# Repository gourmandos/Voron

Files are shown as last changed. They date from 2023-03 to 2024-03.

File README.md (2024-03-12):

This repo is a collection of the info gathered in preparationa dn during the completion fo my built, hopefully it serves others.  
As always, make your own choices - the Trident is a great machine in it's stock form, none of this is necessary.

# [RESOURCES](/Resources.md)

General stuff

# [ACCESORIES & MODS](/ThingsToPrint.md)

Things to print

# [ELECTRONICS](/Electronics.md)

## [Wiring](/Electronics.md#wiring)

# [RPI STUFF](/RPi.md)

# [CONFIG STUFF](/Klipper&Config.md)

# [WHERE TO BUY](/$$$.md)

---

# MODS

[ADXL Nozzle mount](https://github.com/Armchair-Engineering/ADXL-Mounts)

[Printed top hat](https://github.com/jakub874/Jakub3DPrinterMods/tree/main/Tophat)

## Purge & Scrub

> UPDATE [HERE](https://discord.com/channels/712144492563791922/712144492563791925/1103200498649145364)

https://www.printables.com/model/174526-trident-mount-for-decontaminator-purge-bucket-nozz  
https://drive.google.com/drive/folders/1WdAFon_ZR4lkPwNxH9pqIMwNEeP3NHKx

To be used in combination:

[Double wiper decontaminator](https://drive.google.com/drive/u/0/folders/1z-9KpVIce1BrdW45PiMQcnK1v2ausvbj)  
Credits @Sushei#3125 on Discord

[Trident decontaminator mount](https://www.teamfdm.com/files/file/617-trident-decontaminator_mount_rightstl/)

[Macros](https://github.com/VoronDesign/VoronUsers/tree/master/orphaned_mods/printer_mods/edwardyeeks/Decontaminator_Purge_Bucket_&_Nozzle_Scrubber/Macros)

[Jig](/stl-3mf/Wiper_Jig.stl) for cutting the icetray made wiper.

[Voron Trident Silicone Nozzle Park](https://github.com/Esoterical/PrinterMods/tree/main/Trident%20Nozzle%20Park)

## Exhaust

[Magnetic Exhaust Grill Cover](https://github.com/VoronDesign/VoronUsers/tree/master/printer_mods/falo/magnetic_grill_cover)

[VEFACH - Voron Exhaust Filter Activated Coal + Hepa](https://mods.vorondesign.com/detail/aLS5rOxzGybD4FhVzCKNQ)

[Exhaust Adapter 100mm](https://mods.vorondesign.com/detail/nKx3H8zQ6brp42wN5cgA)

[Exhaust cover with pneumatic passthrough](https://github.com/VoronDesign/VoronUsers/tree/master/printer_mods/Fiction/Exhaust_cover)

[LDO exhaust cover](/stl-3mf/LDO_exhaust_cover.3mf)  
Source: [LDO Trident repo](https://github.com/MotorDynamicsLab/LDOVoronTrident/tree/master/STLs/Angled%20Exhaust%20Cover)

[Roomba 800/900 HEPA Filter Box](https://www.teamfdm.com/files/file/740-voron-24-roomba-800900-hepa-filter-box/)

## Insulation support clips

Used to hold insulation on the inside against the PC panels --- UNTESTED !!!  
[Deck Panel Support Clips](https://github.com/VoronDesign/VoronUsers/tree/master/printer_mods/wile-e1/Deck_Panel_Support_Clips)

## Electronic bay

[Trident Inverted Electronics Bay](https://github.com/VoronDesign/VoronUsers/tree/master/printer_mods/LoganFraser/TridentInvertedElectronics)

[SSD DIN mount](/stl-3mf/SSD%20DIN%20mount/), inspired from [SSD DIN bracket](https://github.com/VoronDesign/VoronUsers/tree/master/printer_mods/slitte/ssd_bracket)

[Pi fan with SSD mount](https://www.printables.com/model/225282-the-terrapi-x-prusa-edition-single-ssd-case-for-ra)

[Screw terminal cover for LRS PSU](https://github.com/VoronDesign/VoronUsers/tree/master/printer_mods/samwiseg0/lrs_screw_terminal_cover)

[Cable tie mount for DIN rail](https://github.com/VoronDesign/VoronUsers/tree/master/printer_mods/aeresov/cable_tie_DIN_mount)

[Cable tie double-sided tape anchor](/stl-3mf/Ziptie%20DS-tape%20cable%20anchor.3mf)

[Stiffer generic DIN bracket](https://github.com/Ramalama2/Voron-2-Mods/tree/main/DinClips)

[AliExpress Wagos DIN bracket](https://github.com/VoronDesign/VoronUsers/tree/master/printer_mods/Empusas/Terminal_Blocks_NC933_SPL-62)

[Octopus Pro FanCase aka Octoglasses](https://github.com/Ramalama2/Voron-2-Mods/tree/main/Octopus_Pro_FanCase)

[Octopus driver cooling](/stl-3mf/Octopus%20driver%20cooling/)
Credits to BioShank (Discord)

[Misumi Cable Clip](https://github.com/Ramalama2/Voron-2-Mods/tree/main/Misumi_Cable_Clip)

[Cable duct](https://github.com/GP3DS/Voron-Mods/tree/main/Cable_Duct)

[Cable canal](https://www.thingiverse.com/thing:3062013)

[Remix of RyanDam's Cable Management Duct](https://www.teamfdm.com/files/file/724-remix-of-ryandams-cable-management-duct-for-voron-printers/)

## Skirts

[Integrated accent mesh](https://www.youtube.com/watch?v=K6sHfXldK4k)

[ADXL keystone](https://www.teamfdm.com/files/file/358-adxl345-skirt-keystone/)

[Trident right skirt switch](https://github.com/VoronDesign/VoronUsers/tree/master/printer_mods/DerekBackus/Right_Skirt_Switch)

[Skirt push buttons - *Bouncy Mouse*](https://github.com/Jaans/Voron-Printer-Mods/tree/main/Bouncy-Mouse)

## Screen mount

[Waveshare 5'' screen](/stl-3mf/Waveshare%205''%20screen.3mf)

Fits [5inch DSI LCD](https://www.waveshare.com/wiki/5inch_DSI_LCD) model - Remixed from [sttts](https://github.com/VoronDesign/VoronUsers/tree/master/printer_mods/sttts/Waveshare-5.5-inch-HDMI-AMOLED) & [Paul_GD](https://www.printables.com/model/178195-waveshare-5-dsi-touchscreen-for-bear-21)

## LEDs

[Daylight bracket 2020](https://github.com/VoronDesign/Voron-Hardware/blob/master/Daylight/STL/Brackets_2020.stl)

[LED clip, by eddietheengineer](https://github.com/VoronDesign/VoronUsers/blob/master/printer_mods/eddie/LED_Bar_Clip)

[LED corner, by Ramalama](https://github.com/Ramalama2/Voron-2-Mods/tree/main/Deprecated/Misumi_Led_Corners)

[Voron 2.2 led light bar mount](https://github.com/VoronDesign/Voron-2/blob/Voron2.2/STLs/VORON2.2/Misc)

[Rainbow BARF SB logo](https://github.com/tanaes/whopping_Voron_mods/tree/main/LEDs/Rainbow_Barf_Logo_LED)

[LED baffles](https://github.com/AdamV3D/V3D-Voron-Mods/tree/main/Daylight_on_a_Stick/Mounts/V2.4/V2)

## Doomy

[Sidepack](https://github.com/3DPrintingMods/VoronTrident-Sidepack)

[EZ Bake](https://github.com/FrankenVoron/Trident-EZBake)

## Belted Z

[Orion Tri-belt](https://github.com/bythorsthunder/Orion-Tri-Belt)

[Voron Trident - Belted Z motion](https://github.com/3DPrintingMods/VoronTrident-BeltedZ)

[VT Belted Z](https://github.com/MathematicalPotato/Voron_Mods/tree/main/VT_Belted_Z)

Voron Trident - K3Z

## AWD

[Fourbie](https://github.com/MakerBogans/Fourbie)

[TridentAWD](https://github.com/Fuffledag22/TridentAWD)

aTinyShellScript Voron v2.4 AWD [Mod](https://docs.atinyshellscript.com/v2.4/awd/#nema17-bearing-idler-stacks)

Modified version of aTinyShellScript's AWD [MOD](https://mpx.wiki/VORON-AWD-2WD-MOD/intro)

## Filament guide

[Through panel with 360° joint](https://github.com/DeBau/VoronMods/tree/main/Top%20Bowden%20Guide)

[PTFE tube guide with F695 bearing - TOP REAR extrusion](/stl-3mf/Bowden_Guide_-_Long-Arm_v1-F695.3mf)  
Credits to [GalvanicGlaze](https://github.com/GalvanicGlaze/Voron_Mods/tree/main/Trident%20Bowden%20tube%20PTFE%20guide) & [top_gun_de](https://discord.com/channels/460117602945990666/635687829254701107/1026616435805519902) 
    
## Smart Filament Sensor

[SFS V2.0 Pivot Mount](https://www.thingiverse.com/thing:6275328)

[Exhaust cover and BTT Smart Filament Sensor mount](https://github.com/VoronDesign/VoronUsers/tree/master/printer_mods/Fiction/Exhaust_cover_SFS)

[BTT Smart Filament Sensor frame mount](https://github.com/airway38/Voron-Modifications/tree/main/BTT%20SFS%20Frame%20Mount)

[BTT Smart Filament Sensor mount](https://www.printables.com/model/220585-voron-v2-btt-smart-filament-sensor-mount)

[BTT filament motion sensor mount](https://github.com/VoronDesign/VoronUsers/tree/master/printer_mods/Empusas/BTT_Filament_Motion_Sensor_Mount)

## Extruder

[Sherpa Crew Mini](https://github.com/jrlomas/Sherpa-Crew-Mini) - The issue 6/602 slayer

[Fixed Idler Sherpa Micro](https://github.com/Annex-Engineering/Annex-Engineering_User_Mods/tree/main/Extruders/Sherpa_Micro/Extruder_Mods/Churls_Fixed_Idler_Micro)

# ACCESORIES

## Filter

[Rebreather_XL](https://github.com/Annex-Engineering/Annex-Engineering_User_Mods/tree/main/Misc/Rebreather/Kirby-RebreatherXL)

Trident mount [HERE](/stl-3mf/Rebreather%20XL/)

> Credits to `UPDATE`

[Nevermore Micro v6](https://github.com/nevermore3d/Nevermore_Micro/tree/master/V6)  
>Community nods available `TO BE UPDATED`

[Nevermore StealthMax](https://github.com/nevermore3d/StealthMax) with [direct-mount onto a panel](https://github.com/nevermore3d/StealthMax/tree/main/STL/Direct-On-Panel_Mount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)

[Rebreather](https://github.com/Annex-Engineering/Rebreather)

[The_Filter](https://github.com/nateb16/VoronUsers/tree/master/printer_mods/nateb16/THE_FILTER)

[Activated Carbon Filter 7530](https://github.com/yasuoki/ActivatedCarbonFilter7530)

[Trident shaft](https://github.com/thomas-ewing/trident-shaft)

[Evermore](https://github.com/TodWulff/Evermore-Chamber-Filter)

[MFNano](https://github.com/MapleLeafMakers/MFNano)

## Dust & purge management

[Z-Motor cover](https://www.teamfdm.com/files/file/555-z-motor-cover-trident/?tab=details)

[2020 profile covers](https://mods.vorondesign.com/detail/8PtM9BKgRdBUN7CZ8g6Q)

[6mm slot cover](https://mods.vorondesign.com/detail/ZKJgu7OwMNB1xAKRrYSYeg)

## MMU

[TradRack](https://github.com/Annex-Engineering/TradRack)

[piKa - filament buffer](https://github.com/geoffrey-young/pika-filament-buffer)

## Cam

[Angry CAM USB](https://mods.vorondesign.com/detail/RYpQW53mtem8Nj1JKqiSQ)

[Modified PanzerObserver from Slidr](https://github.com/hartk1213/MISC/tree/main/Voron%20Mods/Non%20Printer%20Voron%20Stuff/Voron_Camera)

## CPAP Muffler 

[Mammoth design](https://github.com/Mammoth-3D/Mammoth-FDM-MODs/tree/main/Mammoth%20CPAP%20Muffler/Voron%203D%20Printers)

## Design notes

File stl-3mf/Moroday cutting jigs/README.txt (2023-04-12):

You need to print all 4 jigs.

XXmm represents the starting width of the tape.

To use cut a lenght of foam tape slightly longer than the final lenght you need.
Place the cutting guide on the tape, and insert a craft knife / razer in the slot.
I found a combination of sliding the jig while slightly pullingl the foam worked best to get a clean cut.
Once cut in 1 direction, rotate the jig 180 degrees and cut in the other direction. 
The cut lines should meet up.

Use 24mm_guide first, it will result in a 19mm strip and a 5mm strip

Use 19mm_guide second, it will result in a 14mm strip and a 5mm strip.

Use 14mm_guide third, it will result in a 9mm strip and a 5mm strip.

Finally, use the 9mm_guide, it will result in a 4mm strip and a 5mm strip.

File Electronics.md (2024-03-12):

## Octopus Pro Guide

Guide [HERE](https://www.makenprint.uk/3d-printing/3d-printing-guides/3d-printer-mainboard-installation-guides/btt-octopus-guides/btt-octopus-pro-guide/)

## Octopus PinOut

[BTT Octopus Pro v1.0 F429](https://teamgloomy.github.io/btt_octopus_pro_1.0_f429_pins.html)

BTT Octopus Pro v1.0 F446/F429  
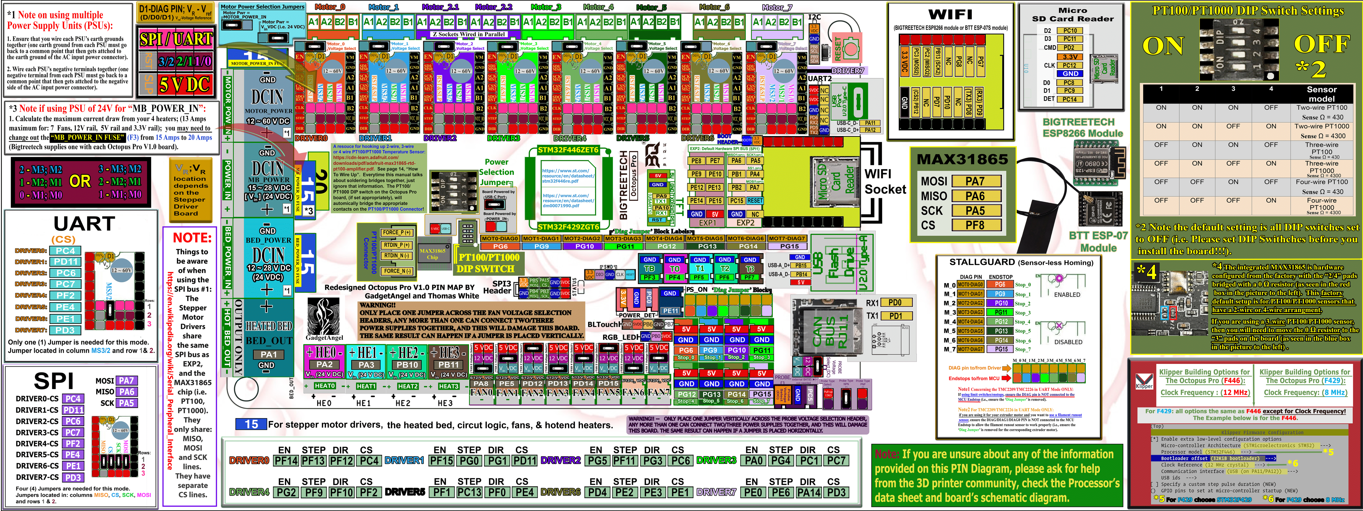
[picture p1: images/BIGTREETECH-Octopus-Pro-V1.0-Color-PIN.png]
BTT Octopus Pro Pins


## Octopus Firmware Flashing

[Instructions](https://github.com/VoronDesign/Voron-Documentation/blob/main/build/software/octopus_klipper.md)

Use MicroSD method!

## Wiring

D2F Switch [Datasheet](/images/D2F_DS.pdf)

[Stepper motor](/images/4wireMotor.png)  
- don't forget to do continuity check to identify pairs
- pairs should have around 1.5 to 2.5 ohms
- if very loud, swap the 2 middle wires

You also can spin the motor by hand, and short pairs until it stalls. Then you know what’s what, and flip direction in software.

[Octopus Pro probe port](https://gadgetangel.org/build/electrical/OctopusPro_ProbePort)

[ 4-pin computer PWM fan on the BTT Octopus](https://www.nicksherlock.com/2022/01/driving-a-4-pin-computer-pwm-fan-on-the-btt-octopus-using-klipper/)

[Connecting a 4028 server fan](https://os.ratrig.com/docs/guides/4028/)

## Microswitch Z Endstop 

[GitHub Instructions / Design](https://github.com/VoronDesign/Voron-Hardware/tree/master/Microswitch_Z_Endstop) & [AliExpress PCB](https://www.aliexpress.com/item/1005005223120516.html)

## JST XH Fan Splitter

2 pins JST XH splitter 4 ways [here](/other/XH-Splitter_gerbers.zip)

Credits to [xbst](https://github.com/xbst/Random-PCBs/tree/master)

[Tutorial for designing a PCB](https://www.circuitbasics.com/make-custom-pcb/)

## Additional PwM fans board

[TinyFan](https://github.com/Gi7mo/TinyFan)

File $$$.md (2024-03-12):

## Cable Management

[Rigid Open Slotted Cable Duct ](https://www.tradezone.com.au/product/nhp-25mm-x-30mm-x-2-metres-rigid-open-slotted-cable-duct-21104.html)

## CAN cable

[IGUS chainflex® CF113.D](https://www.igus.com.au/product/CF113_D?artnr=CF113.018.D)

## WiFi relay

[Shelly Plus 1PM](https://smartguys.com.au/smart-lighting/shelly-plus-1pm.html)

## Activated charcoal

NOT acid washed

[2kg Virgin Activated Coconut Shell Carbon](https://www.clarencewaterfilters.com.au/product/voc-removal-from-air-coco-a55-4x8-mesh-gac-carbon/)  

[2kgs 4mm Activated Carbon Pellets COL PA-60](https://www.clarencewaterfilters.com.au/product/4mm-activated-carbon-pellets-for-air-and-water-purification/)

## 100kΩ Glass NTC Thermistor

[JayCar](https://www.jaycar.com.au/100k-glass-ntc-thermistor/p/RN3446)

## Metal parts

[Gantry](https://github.com/3DPrintingMods/VoronTrident-AluminumG)

## Xol PCB

[PCB](https://github.com/ruiqimao/VoronStuff/tree/main/Xol_PCB) made for Armchair Engineering's [Xol Toolhead](https://github.com/Armchair-Engineering/Xol-Toolhead)

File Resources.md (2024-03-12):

# Resources

## Guides

[Learn GIT](https://learngitbranching.js.org/)

[Formatting on github](https://docs.github.com/en/get-started/writing-on-github/getting-started-with-writing-and-formatting-on-github/basic-writing-and-formatting-syntax)

[MarkDown - Getting started](https://www.markdownguide.org/getting-started/)

[WireViz - easy documenting for cables, wiring harnesses and connector pinouts](https://github.com/formatc1702/WireViz)

[Klipper Macros Beginners Guide](https://docs.vorondesign.com/community/howto/voidtrance/Klipper_Macros_Beginners_Guide.html)

[Klipper calculator - Calculating anything Klipper](http://docs.zerog.one/universal/klippercalculator)

[Flow Rate Calculator](https://www.advanced3dprinting.com/flow-rate-calculator/)

---

## CAD

[Voron Construct](https://github.com/PrintersForAnts/Voron-Construct)

[Voron Construct Fusion 360 Add-In](https://github.com/MapleLeafMakers/VoronConstruct360)

---

## Bed adhesive / release agent

[General Goop recipe](https://github.com/MakerBogans/docs/wiki/Printer-goop)

50% water, 50% ipa/metho, 1% pvp/pa by weight

---

## TMC driver current

Quick formula for stepper motor maximum voltage:

```
run_current = motor_peak_current * 0.707 * 0.80
```

## Automated probe accuracy testing

A collection of tests to help checking probe accuracy, precision and drift under different conditions [HERE](https://github.com/sporkus/probe_accuracy_tests)

## Input Shaping / Resonance / Belt Tension

[Klippain Shake&Tune Module](https://github.com/Frix-x/klippain-shaketune)

[Interpreting the Input Shaper Graphs ](https://klipper.discourse.group/t/interpreting-the-input-shaper-graphs/9879)

[ResHelper](https://github.com/lhndo/ResHelper)

Use Klipper to tension the belts, Discord message [HERE](https://discordapp.com/channels/712144492563791922/712144816707731456/1099543025836892281)

[Frequency testing](https://gist.github.com/kmobs/f6def5db272ca5c1b81727482f53bed8)

## Frequency Tester

Test a specific frequency that you hear when you do your resonance testing in Klipper.  
Link [HERE](https://gist.github.com/kmobs/f6def5db272ca5c1b81727482f53bed8)

## Spoolman

Keep track of your inventory of 3D-printer filament spools, see [HERE](https://github.com/Donkie/Spoolman)

## SETUP

### CanBUS / Katapult

[Esoterical guide](https://github.com/Esoterical/voron_canbus)

[How to Use CAN Toolhead Boards Connected Directly to Octopus](/other/How%20to%20Use%20CAN%20Toolhead%20Boards%20Connected%20Directly%20to%20Octopus.pdf)   -   Source [HERE](https://www.teamfdm.com/forums/topic/672-how-to-use-can-toolhead-boards-connected-directly-to-octopus-octopus-pro-on-canboot/)

[maz0r guide](https://maz0r.github.io/klipper_canbus/)

[USB to CAN bus bridge mode](https://www.klipper3d.org/CANBUS.html#usb-to-can-bus-bridge-mode)

### Fixing a wonky bed mesh

Discord message [HERE](https://discord.com/channels/460117602945990666/551488536256184331/1023369753470980197)

---

### Rotation_distance on extruders

>initial_mark_distance = initial mark on filament from the intake of the extruder body
subsequent_mark_distance = distance of mark on filament after extruding 100mm
actual_extrude_distance = <initial_mark_distance> - <subsequent_mark_distance>
actual_extrude_distance = 120mm - 20mm

```
rotation_distance = <previous_rotation_distance> * <actual_extrude_distance> / <requested_extrude_distance>

rotation_distance = 200 * 20mm / 100mm
```

### Misc
---

[Chamber Temperature & Exhaust Fan](https://github.com/eddietheengineer/VoronDocs/blob/master/setup/additional/chamber_temperature_exhaust_fan.md)

[Filament Runout Sensor](https://github.com/eddietheengineer/VoronDocs/blob/master/setup/additional/filament_runout_sensor.md)

[Fast gyroid infill](https://github.com/RomRider/klipper-FastGyroidInfill)

---

### Sensorless homing

[EZ Sensorless homing](https://github.com/kyleisah/EZ-Sensorless-Homing)

[Klipper official documentation](https://www.klipper3d.org/TMC_Drivers.html#configure-printercfg-for-sensorless-homing)

[Voron Design documentation](https://docs.vorondesign.com/community/howto/clee/sensorless_xy_homing.html)

[Finding the right StallGuard threshold](https://docs.vorondesign.com/community/howto/clee/sensorless_xy_homing.html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)

---

## CALIBRATION 

[Advance resonance tuning](https://github.com/SnakeOilXY/SnakeOil-XY/blob/master/Doc/Manual/advance-resonance-tuning.md)

[Flow Calculator macros](https://github.com/agentk/klipper_macros/tree/main/FlowCalculator)

[Extrusion system Benchmark](https://github.com/CNCKitchen/ExtrusionSystemBenchmark)

[Bioshank - Flow Test Tool](https://docs.google.com/spreadsheets/d/1owDOOfIYF0fXw-70wJZLp1kmjqjqEDme/edit#gid=2039809214)

[Klippylyzer - Analyze your Klippy logs and more](https://klippylyzer.github.io/)  Github repo [HERE](https://github.com/Klippylyzer/klippylyzer#klippylyzer---analyze-your-klippy-logs-and-more)

---

## TROUBLESHOOTING

In case of under-extrusion, check that the printer/slicer is in relative and not absolute. Add M83 in the slicer if not. See Discord message [HERE](https://discord.com/channels/712144492563791922/712144816707731456/1105794634652844042)

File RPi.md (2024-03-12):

## Cooling

PWM Fan on GPIO guide [HERE](https://forums.raspberrypi.com/viewtopic.php?t=194621)

**ALTERNATIVELY**: Comment out

```
[temperature_sensor RPi]
sensor_type: temperature_host

[temperature_sensor MCU]
sensor_type: temperature_mcu
```

And add

```
[temperature_fan RPi_Fan] 
pin: POPULATE THE CORRECT PIN
max_power: 1.0
shutdown_speed: 1.0
kick_start_time: 0.2
off_below: 0.15
cycle_time: 0.010
sensor_type: temperature_host
control: watermark
min_temp: 0
max_temp: 70
target_temp: 40.0
min_speed: 0.5

[temperature_fan MCU_Fan] 
pin: POPULATE THE CORRECT PIN
max_power: 1.0
shutdown_speed: 1.0
kick_start_time: 0.2
off_below: 0.15
cycle_time: 0.010
sensor_type: temperature_mcu
control: watermark
min_temp: 0
max_temp: 70
target_temp: 35.0
min_speed: 0.5
```

Tmeperatures will remain displayed as standard and the fans are now temperature triggered

## Momentary switch ON/OFF

Connect a switch between PIN 5 (GPIO 3) and 6 (ground) for ON/OFF deep sleep function.  SSH in and type:

```
sudo nano /boot/config.txt
```

Add the following above the **ALL** section at the very end

```
dtoverlay=gpio-shutdown
```

If the Rpi turns ON but not OFF when pressing the push button, try this [solution](https://www.machinistblog.com/raspberry-pi-gpio-power-switch-not-working-solved/)

---

[GPIO 21 & various shutdown behaviours script](https://github.com/maz0r/rpi-shutdown)

[Cable, pinout & instructions](https://shop.inux3d.com/en/home/143-218-terrapi-power-button-.html#/11-color-black)

[LED status](https://embeddedcomputing.com/technology/open-source/development-kits/raspberry-pi-power-up-and-shutdown-with-a-physical-button)

## SSD instead of MicroSD

Guide [HERE](https://www.makeuseof.com/how-to-boot-raspberry-pi-ssd-permanent-storage/)

## Setup a RPi directory as a network shared folder to easily upload prints

Guide [HERE](https://pimylifeup.com/raspberry-pi-samba/)

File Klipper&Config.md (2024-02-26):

## Temperature monitoring and chamber exhaust

Guide [HERE](https://github.com/eddietheengineer/VoronDocs/blob/master/setup/additional/chamber_temperature_exhaust_fan.md)

## Ellis  macros

[Bed_Fans](https://github.com/VoronDesign/VoronUsers/tree/master/printer_mods/Ellis/Bed_Fans)

[Temperature_Wait](https://ellis3dp.com/Print-Tuning-Guide/articles/useful_macros/replace_m109_m190_with_temp_wait.html)

[Determining Maximum Speeds and Accelerations](https://ellis3dp.com/Print-Tuning-Guide/articles/determining_max_speeds_accels.html)

## PID controlled bed fans

Guide [HERE](/other/PID%20controlled%20bed%20fans.md)

## Replace M109/M190 With TEMPERATURE_WAIT

This just makes Klipper resume immediately after reaching temp. Otherwise it waits for the temperature to stabilize.
Guide [HERE](/other/PID%20controlled%20bed%20fans.md)

## Back up printer configuration files to GitHub

Guide [HERE](https://docs.vorondesign.com/community/howto/EricZimmerman/BackupConfigToGithub.html) & alternate guide [HERE](https://lazarofilm.gitbook.io/3d-printing/creating-a-github-backup-for-klipper)

## Autocommit config changes to github

Guide [here](https://github.com/th33xitus/kiauh/wiki/How-to-autocommit-config-changes-to-github%3F)

## Sonar - network pinger

Keep the WiFi connection alive by pinging at interval, instructions [HERE](https://github.com/mainsail-crew/sonar)
Included in Mainsail OS - just remember to change the ```enable:``` option to **TRUE**

## Auto Z Calibration

Repo [HERE](https://github.com/protoloft/klipper_z_calibration)

## A better print_start macro

Repo [HERE](https://github.com/PrintStructor/A-better-print_start-macro)

## Interruptible HEATSOAK macro

[ReadMe](https://github.com/garethky/klipper-voron2.4-config/blob/mainline/printer_data/config/heatsoak.readme.md)

## Setup a BTT Smart Filament Sensor

Set the sensitivity to 10 minimum

[Setup a BTT Smart Filament Sensor](zhttps://docs.vorondesign.com/community/howto/samwiseg0/btt_smart_filament_sensor.html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)

## Automated probe accuracy testing

Instructions [HERE](https://github.com/sporkus/probe_accuracy_tests)

## LED

[Rainbow barf logo for SB](https://github.com/tanaes/whopping_Voron_mods/tree/main/LEDs/Rainbow_Barf_Logo_LED)

[LED Effects for Klipper](https://github.com/julianschill/klipper-led_effect)

## Klipper Estimator

Repo [HERE](https://github.com/Annex-Engineering/klipper_estimator)

## Adaptive Bedmesh

[KAMP](https://github.com/kyleisah/Klipper-Adaptive-Meshing-Purging)

[Klippain](https://github.com/Frix-x/klipper-voron-V2/blob/main/doc/features/adaptive_bed_mesh.md)

## Driver Tuning

[Klipper TMC Autotune](https://github.com/andrewmcgr/klipper_tmc_autotune)  
***WARNING*** if sensorless homing, `sg4_thrs` and/or `sgt` values need to be readjusted

[DrGhetto's guide for Klipper](https://github.com/MakerBogans/docs/wiki/TMC-Driver-Tuning)

## Useful sets of macros

[Ellis](https://ellis3dp.com/Print-Tuning-Guide/articles/index_useful_macros.html)

[The-Conglomerate](https://github.com/The-Conglomerate/Voron-Klipper-Common/)

[jschuh](https://github.com/jschuh/klipper-macros/tree/main)

## SS PLA Profile

[Example](https://gist.githubusercontent.com/cmidgley/d6bb5e894def0794fa3e1f154e794aaa/raw/723e58910d8efdbd86f0f36f43d770f766422ba4/Voron%252024%2520SuperSlicer.ini)

## PA per nozzle

```
; Set pressure advance per-filament for different nozzle sizes
{if nozzle_diameter[0]==0.4}SET_PRESSURE_ADVANCE ADVANCE=0.04  SMOOTH_TIME=0.02
{elsif nozzle_diameter[0]==0.5}SET_PRESSURE_ADVANCE ADVANCE=0.03 SMOOTH_TIME=0.02
{elsif nozzle_diameter[0]==0.6}SET_PRESSURE_ADVANCE ADVANCE=0.01  SMOOTH_TIME=0.02
{elsif nozzle_diameter[0]==0.8}SET_PRESSURE_ADVANCE ADVANCE=0.01 SMOOTH_TIME=0.02
{endif}
```

## Extrusion roles - Fast Infill

Discord Message [HERE](https://discord.com/channels/712144492563791922/712144816707731456/1080119195158708276)

## KlipperScreen

Change KlipperScreen background [Instructions](https://www.teamfdm.com/files/file/690-klipper-screen-blue-hexes/)

RPi BUSTER [Instructions](/other/Pi%20Buster%20KlipperScreen%20Instructions)

No TouchScreen FIX [Instructions](/other/No%20touchscreen%20fix)

## TailScale

For Mainsail: MUST add the IP of the device intending to connect with in Moonraker.conf

[Source](https://www.teamfdm.com/forums/topic/1594-tailscale-vpn-and-mobile-raker/)

[Example](https://github.com/ihrapsa/KlipperWrt/issues/21)

Alternatively, try [MobileRaker](https://github.com/Clon1998/mobileraker)

## Syncing slicer profiles

**SUPERSLICER**

[Youtube tutorial](https://www.youtube.com/watch?v=n_8kIZWBjhY&t=195s)

add the `--datadir c:/my/local/dir` parameter to **SS.exe** shortcut

**PRUSASLICER**

Tutorial [HERE](https://adambyram.com/2023/01/29/syncing-prusaslicer-configuration/)

## Thermistor Heatsink Failsafe

```
[temperature_sensor Heatsink_failsafe]
sensor_type: Generic 3950
sensor_pin: expander:PA5
max_temp: 85
```

**OR**

[Hotend Fan RPM Monitoring](https://ellis3dp.com/Print-Tuning-Guide/articles/useful_macros/hotend_fan_monitoring.html)

## Talking Voron

This is a procedure to have audio files to play throughout your macros. 

Guide [HERE](https://github.com/maclakey/Voron2.4-Mods/tree/main/Talking_Voron)

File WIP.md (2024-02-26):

# WIP

Just my own tracking, no public relevance.

## Physical mods

---

- ~~Inverted electronics~~
- ~~Rama idlers~~
- Carbon fibre X extrusion
- Sleeves & cable management
---

- ~~DB / Sherpa SLS~~
- ~~RKE~~

>Note the rk-rearmount with the little 'hook' that holds the Z chain away from the ribbon, only for v2.4  
If ribbon is drooping, use 2x rk-frontmount swivels on X rail, instead of 1 + fence.  
See [discord pictures](https://discord.com/channels/712144492563791922/888001568568393820/1070332922583859272)  
Alternatively, use [bearing swivels](https://github.com/MakerBogans/roadkill/tree/main/usermods/Usernametaken/Bearing-Shaft) with 2 x f623 bearings, a .5mm shim, m3 nut and an m3 BHCS (length to be adjusted as required).
- ~~Eureka~~

---

- ~~Y support~~
- ~~K3 Door~~
- ~~Panel clips~~

---

- Purge bucket / scrubber
- ~~Chamber thermistor~~
- Air circulation
- Air filtration
- Driver cooling

---

- ~~LED~~
- ~~LED diffusers~~
- ~~Internal spool~~

## Electronics

- ~~Pi Klipperscreen~~
- ~~Config autobackup~~
- Nevermore if ABS...
- Heatsoak macro
- Skirt buttons (light 30% to 100%, up/down babystep, momentary ON/OFF, pause)

## Klipper

- Go over ALL the .cfg  
Use official references such as [Sherpa_Micro](https://github.com/Annex-Engineering/ANNEX-Printer-Firmware/blob/main/Klipper_and_Klipper_Derivatives/Sherpa_Micro/Klipper_Config_Block.txt) when possible

- Virtual Z Endstop:
(When using the probe as the Z endstop)

    Enter ``Z_OFFSET_APPLY_PROBE*``
    This will apply your new offset to your probe’s z_offset.  
    Enter ``SAVE_CONFIG``.

## Potential

- Insulation
- AWD
- Squash ball feet
- 4040 frame
- Belted Z
- [Filametrix](https://github.com/sorted01/Filametrix) with TradRack

## To be sorted

[MEASURE_AXES_NOISE numpy error](https://www.reddit.com/r/klippers/comments/t7dfz0/measure_axes_noise_numpy_error/)

[Sync PS profiles with GitHub](https://forum.prusa3d.com/forum/prusaslicer/prusa-slicer-cloud-settings-sync-settings-between-pcs/)

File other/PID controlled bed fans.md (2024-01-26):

Credits to Deutherius V2.818 (VORONDesing Discord)

[Source](https://discord.com/channels/460117602945990666/1021908552702505051/1129498299272011866)

Main idea is to tell klipper that those bed fans are actually a chamber heater.  
Spicy fans usually work with a constant fan and switching heater. This is similar, but in reverse - bed heater makes sure that the bed itself stays at a constant temperature and fans get PWMed to draw varying amount of heat from the bed heater.

```
[heater_generic heater_chamber]
heater_pin: z:P2.5
sensor_type: ATC Semitec 104NT-4-R025H42G
sensor_pin: P0.25
control: pid
pid_Kp: 61.470837
pid_Ki: 0.5
pid_Kd: 0
pwm_cycle_time: 0.3
min_temp: -273.15
max_temp: 75

[verify_heater heater_chamber]
max_error: 120
check_gain_time: 120
hysteresis: 50
heating_gain: 1

[gcode_macro SET_CHAMBER]
gcode:
  {% set chamber_target = params.CHAMBER_TEMP|default(0)|float %}
  SET_HEATER_TEMPERATURE heater=heater_chamber target={chamber_target}
  ```

**heater_pin** is what the bed fans plug into  
**sensor_pin** is a thermistor somewhere in the chamber, preferably shielded from things that can influence local chamber temp (part cooling fan being the most obvious)  
**verify_heater** section is there so that klipper doesn't die when chamber temp gets set while the bed is cold or heating up (heater not heating at expected rate error). Do not play with this code block for any other heater, it's a real fire hazard. Here it's safe because nothing can really thermally run away (bed heater is controlled separately by a different PID loop). Worst that can happen is that the bed fans can overpower the bed heater and cause a thermal runaway shutdown - you can set a lower max "heater" (fan) power for your specific system to combat that issue.

You can try automatic PID tuning for the system, but I wouldn't bother - it took me something close to 4 hours and the values didn't work really well - the super high D value (>4700) caused the bed fans PWM to be extra jumpy, going +-30% PWM multiple times a second. Values I ended up with should be relatively robust and the PWM changes are steady.

This is the relevant part of my print_start:

```
    {% set CHAMBER_TEMP = params.CHAMBER_TEMP|default(0)|float %}

        ...

        STATUS_HEATING

        M140 S{BED_TEMP|int} ;start heating up bed

        {% if FILAMENT_TYPE == "ABS" or FILAMENT_TYPE == "ASA" or FILAMENT_TYPE == "PC" %}
            SET_FAN_SPEED FAN=Nevermore_micro SPEED=0.6
            SET_FAN_SPEED FAN=Exhaust SPEED=0.25   
        {% endif %}

        M104 S150 #start heating up nozzle

        {% if CHAMBER_TEMP > 0 and not printer["heater_generic heater_chamber"].temperature >= CHAMBER_TEMP|float%} #wait for chamber temps
            SET_CHAMBER CHAMBER_TEMP={CHAMBER_TEMP+1} #+1 °C for faster temp target arrival
            CENTER
            M106 S204 #part cooling fan 80%
            TEMPERATURE_WAIT SENSOR="heater_generic heater_chamber" MINIMUM={CHAMBER_TEMP-0.1} #wait until chamber temp is very nearly reached
            SET_CHAMBER CHAMBER_TEMP={CHAMBER_TEMP} #set correct chamber target and let PID do its magic
            STATUS_CLEANING
            CLEAN_NOZZLE
        {% endif %}

        #in case chamber was already heated
        {% if CHAMBER_TEMP > 0 %}
            SET_CHAMBER CHAMBER_TEMP={CHAMBER_TEMP} 
        {% endif %}
        
        M107 #part cooling fan off
        #make sure hotend and bed are up to temp in all cases
        M109 S150
        M190 S{BED_TEMP|int}
```

and of course pass the chamber temp parameter from slicer, e.g. in superslicer

```print_start EXTRUDER_TEMP=[first_layer_temperature] BED_TEMP=[first_layer_bed_temperature] CHAMBER_TEMP=[chamber_temperature] FILAMENT_TYPE={filament_type[0]}```

EDIT: If you are using the mini12864 display with lcd_tweaks.cfg for a chamber temperature icon on the display, you can modify the cfg file to get the chamber temp readout back by swapping this line  
```{% set chamber = printer['temperature_sensor chamber'] %}```  
for  
```{% set chamber = printer['heater_generic heater_chamber'] %}```

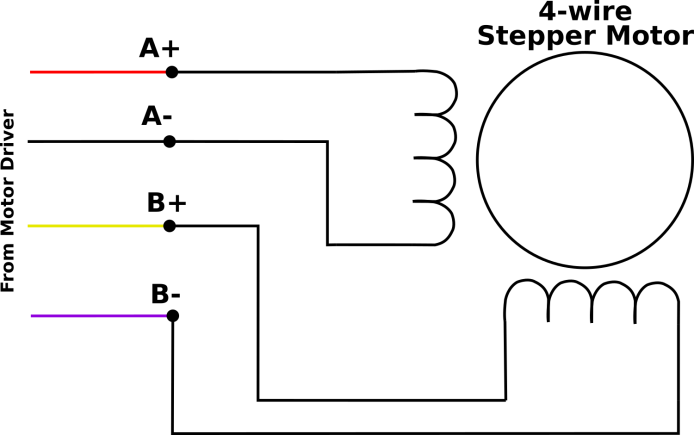
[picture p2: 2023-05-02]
images/4wireMotor.png

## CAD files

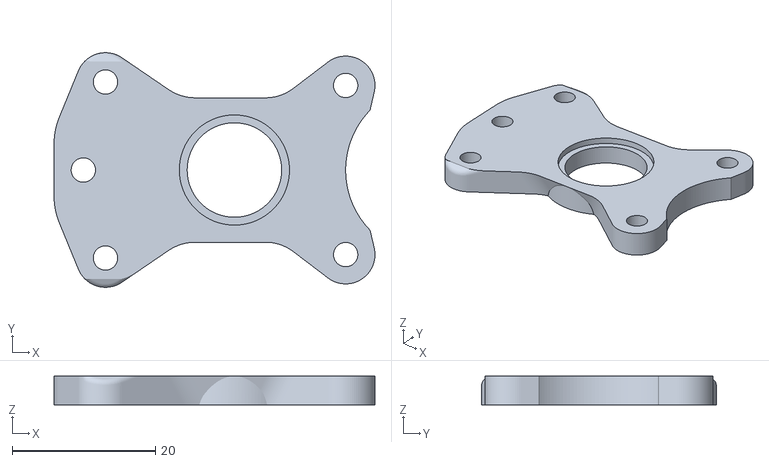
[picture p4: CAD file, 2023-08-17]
stl-3mf/mobius_v3-front_drive_plate.stl
44.9 x 32.8 x 4.00

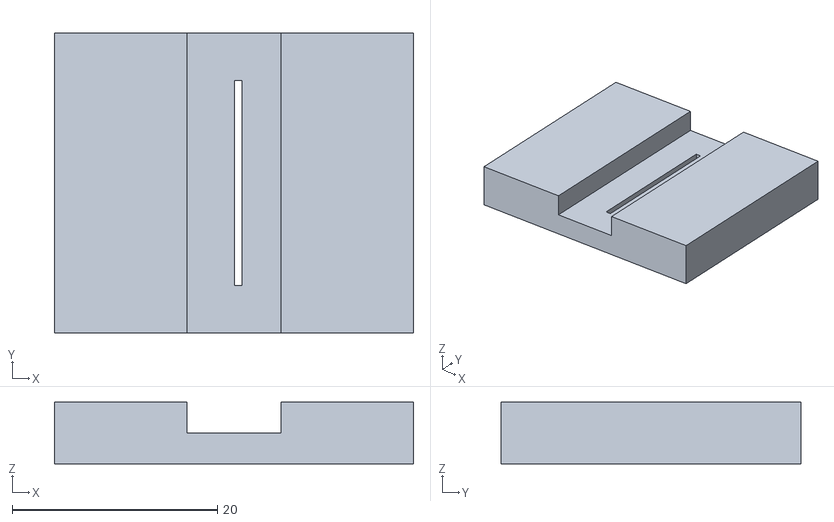
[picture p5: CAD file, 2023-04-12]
stl-3mf/Moroday cutting jigs/9mm_guide.stl
35.0 x 29.2 x 6.00

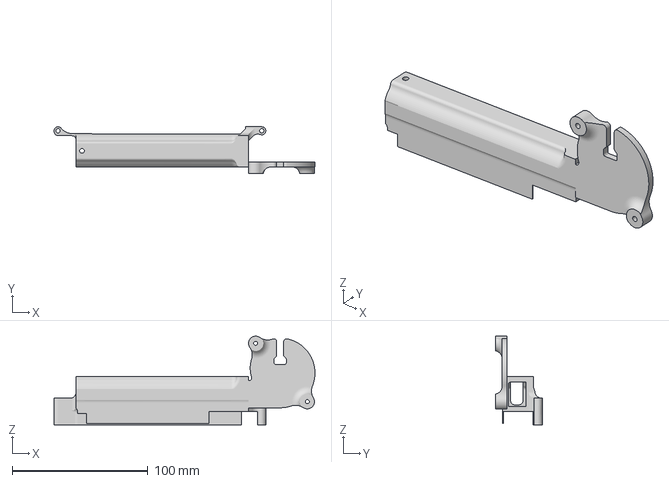
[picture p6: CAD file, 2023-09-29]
stl-3mf/Octopus driver cooling/tunnel_5015.3mf
192.2 x 34.3 x 65.4 mm

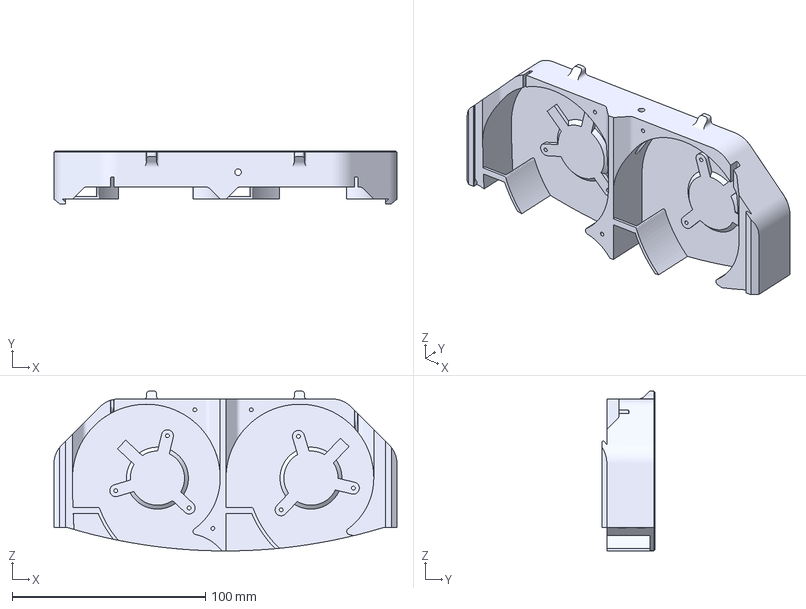
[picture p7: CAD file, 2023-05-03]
stl-3mf/Rebreather XL/Rebreather XL Fan Cartridge - Mod.3mf
177.3 x 27.3 x 82.6 mm

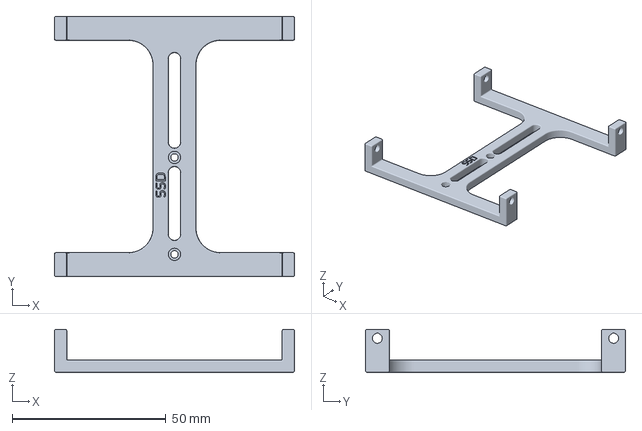
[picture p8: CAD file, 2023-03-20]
stl-3mf/SSD DIN mount/SSD DIN SideMount.3mf
78.0 x 84.6 x 14.0 mm

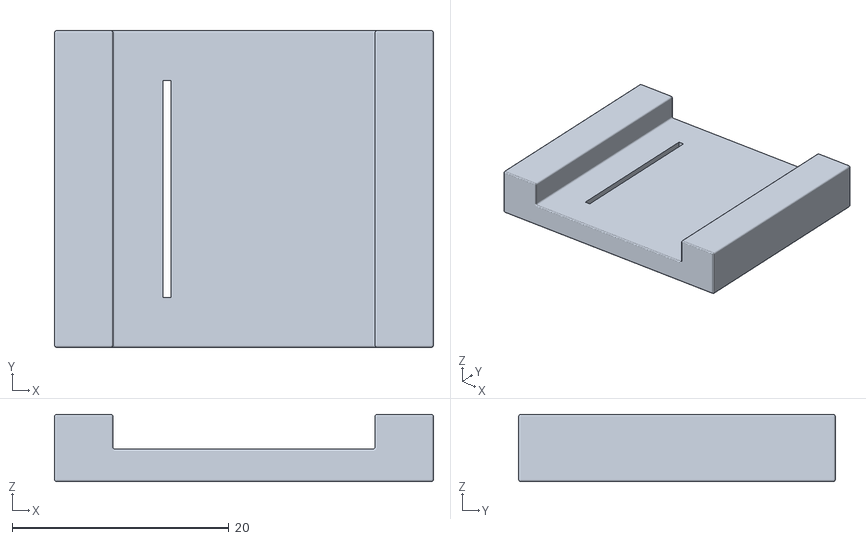
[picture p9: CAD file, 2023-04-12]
stl-3mf/Moroday cutting jigs/24mm_guide.stl
35.0 x 29.2 x 6.20

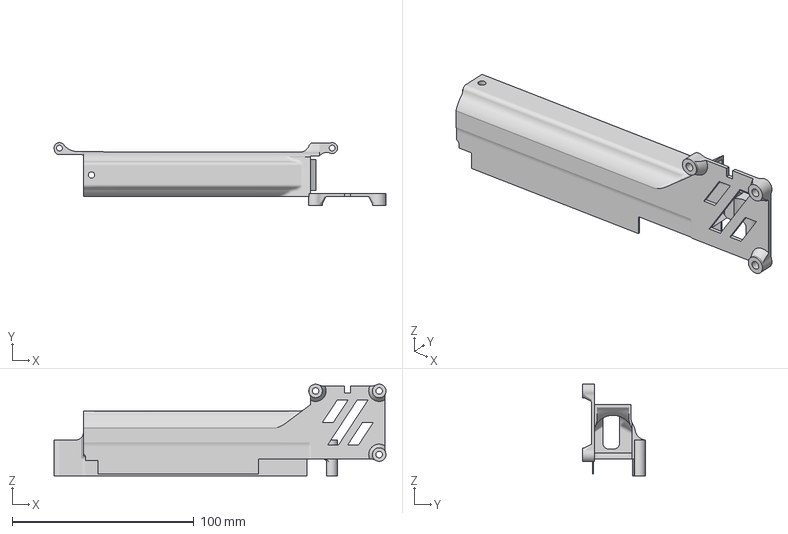
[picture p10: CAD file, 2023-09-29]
stl-3mf/Octopus driver cooling/tunnel_4020.3mf
182.6 x 34.5 x 50.5 mm

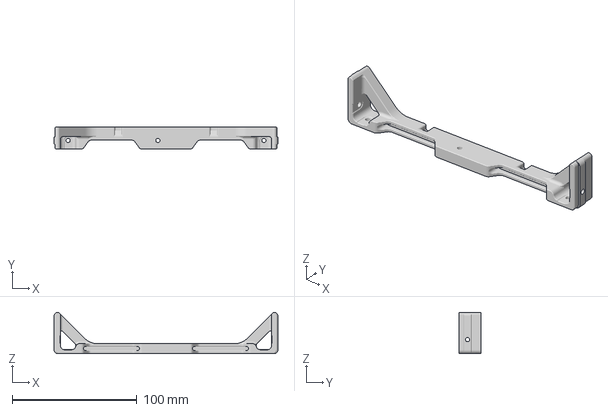
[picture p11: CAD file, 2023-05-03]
stl-3mf/Rebreather XL/Rebreather XL Mount.3mf
179.3 x 17.9 x 32.9 mm

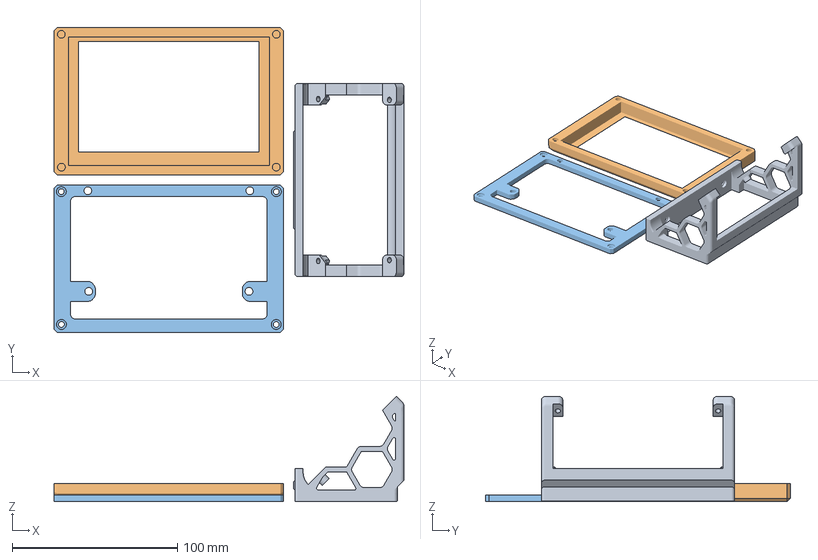
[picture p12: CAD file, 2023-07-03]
stl-3mf/Waveshare 5'' screen.3mf
211.8 x 184.4 x 63.8 mm
Case Mount
Front Case
Bottom Case

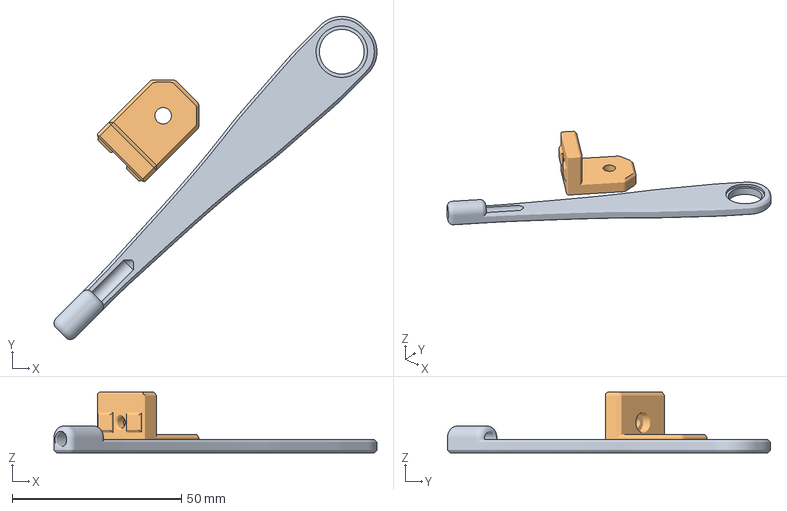
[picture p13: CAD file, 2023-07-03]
stl-3mf/Bowden_Guide_-_Long-Arm_v1-F695.3mf
95.5 x 95.5 x 18.0 mm
Long-Arm_v1-F695.stl
Mount

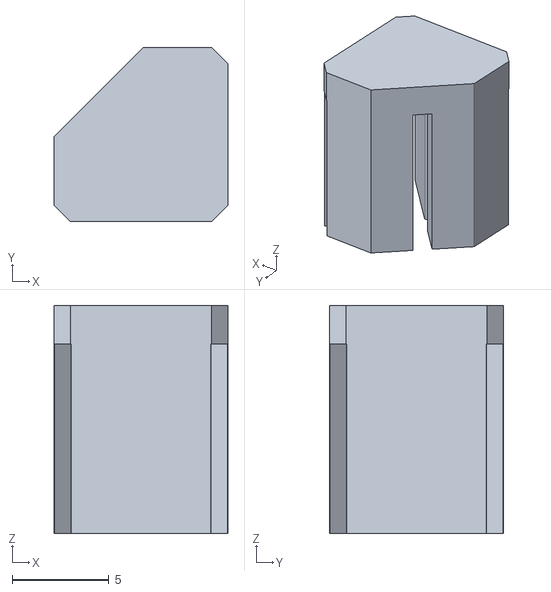
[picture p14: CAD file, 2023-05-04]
stl-3mf/Wiper_Jig.stl
9.00 x 9.00 x 11.8

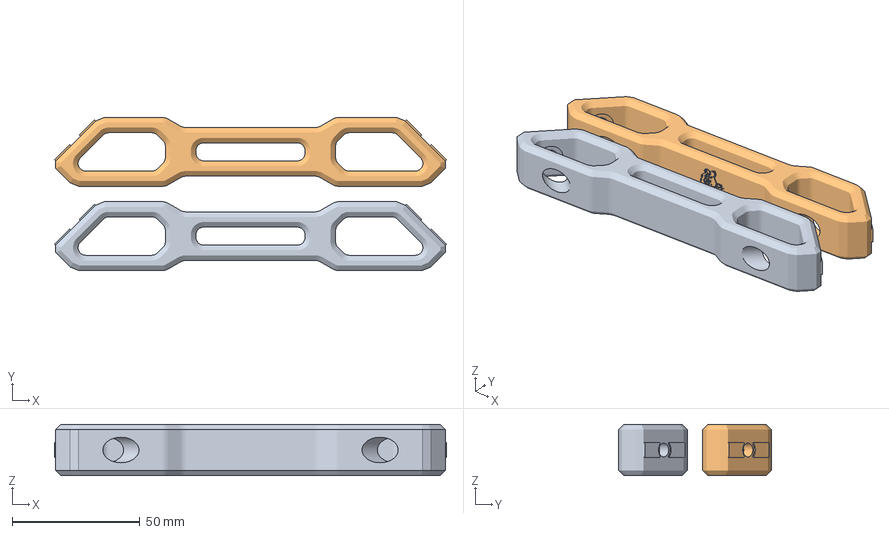
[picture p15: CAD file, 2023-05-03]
stl-3mf/Trident_Y_support.3mf
153.6 x 60.0 x 20.0 mm
Trident Y support - noLogo
Trident Y support - MBLogo

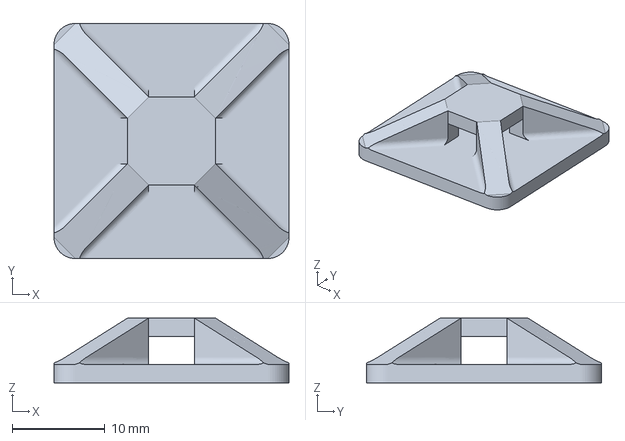
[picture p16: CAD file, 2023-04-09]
stl-3mf/Ziptie DS-tape cable anchor.3mf
25.4 x 25.4 x 7.00 mm

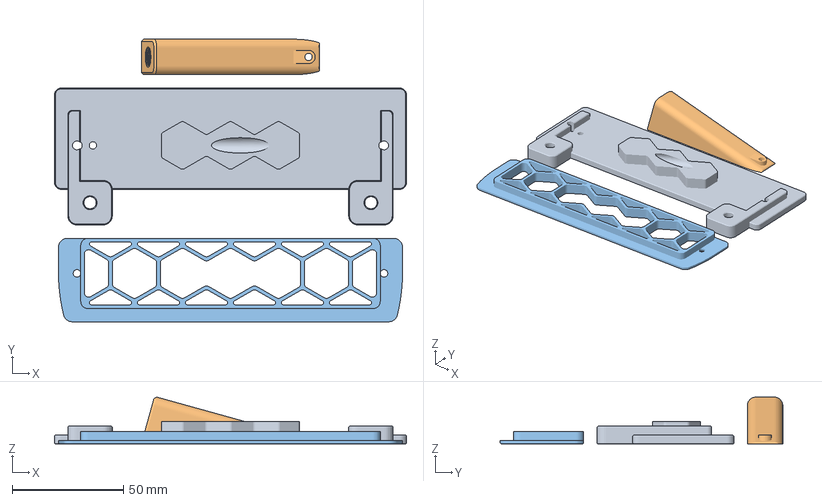
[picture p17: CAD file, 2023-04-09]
stl-3mf/LDO_exhaust_cover.3mf
158.4 x 127.2 x 21.1 mm
exhaust_cover.stl
coupler_mount.stl
exhaust_grill.stl

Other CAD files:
stl-3mf/Moroday cutting jigs/14mm_guide.stl
stl-3mf/Octopus driver cooling/tunnel_5015_no_hole_for_tempProbe.3mf
stl-3mf/Moroday cutting jigs/19mm_guide.stl
stl-3mf/Moroday cutting jigs/foam_tape_cutting_tool v2.f3d
stl-3mf/SSD DIN mount/ssd_bracket v3.f3d

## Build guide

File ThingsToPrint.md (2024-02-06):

## 625 / F695 bearing repacker 

[Revision 2.0](https://github.com/Annex-Engineering/Misc_Designs/tree/master/Bearing_Repacker/Release_2)

## Extruder Calibration 

[Annex E. Stick](https://github.com/Annex-Engineering/Misc_Designs/tree/master/Extruder_Calibration_Stick)

## Nozzle torque wrench

[Option 1](https://www.thingiverse.com/thing:4738816)

[Option 2](https://www.thingiverse.com/thing:4332963)

## Belt tensioning

Mechanical [GT2 belt tension meter](https://github.com/Diyshift/3D-Printer/tree/main/GT2%20Belt%20Tension%20Meter)

Prusa Style [belt tension meter](https://github.com/VoronDesign/VoronUsers/tree/master/printer_mods/Kruppes/Tension_Meter)

## Tuning tests

EM [mobius v3 plate](/stl-3mf/mobius_v3-front_drive_plate.stl)

[Bridging](https://www.thingiverse.com/thing:476845)

V2.4 [Test prints](https://github.com/VoronDesign/Voron-2/tree/Voron2.4/STLs/Test_Prints)

## Temp monitoring

[Rectangle hygrometer - face mount](https://github.com/VoronDesign/VoronUsers/tree/master/legacy_printers/printer_mods/Danowar/Humidity_Sensor_Bracket)

[Thermistor - 2020 mount](https://mods.vorondesign.com/detail/dfRX88k7wwS6tpYlvyCEw)

## Temp management

[Trident Bed Fans](https://github.com/VoronDesign/VoronUsers/tree/master/printer_mods/CannedBass/Trident_Bed_Fans)

## Frame

[Y Support braces](/stl-3mf/Trident_Y_support.3mf)

[Trident Gantry Micro Adjuster](https://github.com/Diyshift/3D-Printer/tree/main/Trident%20Gantry%20Micro%20Adjuster)

## Spool management

[2020 mounted foldable spool holder](https://www.printables.com/model/341479-voron-24-trident-switchwire-foldable-spool-holder/)

[Internal Spool Holder + Bowden Guide](https://www.teamfdm.com/files/file/619-trident-simple-internal-spool-holder-bowden-guide-60degrees-curved/)

[Spool holder for "too close to the wall" printers](https://mods.vorondesign.com/detail/VjlccbeeOuH5iax4AFHA)

[Horizontal Spool Holder](https://mods.vorondesign.com/detail/x2umK6ZcG6l2c5EEM2LQjQ)

## Gridfinity

[Goop pen clip](https://github.com/MakerBogans/BoganParts/tree/main/killcode/GoopPenClip)

## Front idlers

Necessary if upgrading the extruder to [DirtyBird](https://github.com/MakerBogans/dirtybird/)

[BFI - Beefy Front Idlers](https://github.com/clee/VoronBFI)

## Trident Pins Mod

Replaces all the M5 screws for all idlers/pulleys/bearings with 5mm pins [HERE](https://mods.vorondesign.com/detail/C8XJJ0fBGfBFKQZctjKeA)

## Doors

[K3 door](https://github.com/Annex-Engineering/Annex-Engineering_User_Mods/tree/main/Printers/Redoubt/BeunHaas34-Annex_Door)

[Clicky-Clack Fridge Dooor](https://github.com/tanaes/whopping_Voron_mods/tree/main/clickyclacky_door)

[270° hinges](https://github.com/VoronDesign/VoronUsers/tree/master/printer_mods/chrisrgonzales/270_degree_hinge)

[270° hinges - Parametric](https://github.com/LoganFraser/VoronMods/tree/main/ParametricRemovable270Hinges)

[Voron v2.2 quick release front panel](https://github.com/VoronDesign/Voron-2/tree/Voron2.2/STLs/VORON2.2/Panel_Mounting/Front_Panel_Quick_Release/Handles)

## Panel Clips
 
[Annex 2020 panel clips](https://github.com/Annex-Engineering/Annex-Engineering_User_Mods/tree/main/Printers/All_Printers/annex_dev-Panel_2020_Clips_and_Hinges)

[Snap latches 2020](https://github.com/VoronDesign/VoronUsers/tree/master/printer_mods/richardjm/snap-latch-2020)  -- Not as good as Annex's but stay in place when open

## Handles

[Sturdy handles](https://github.com/VoronDesign/VoronUsers/tree/master/printer_mods/jeoje/Sturdy_Handles)

## 0.9 Motors AB

VFAs management at the cost of noise -- only if willing to print slow, 0.9 don't like speed.  
[Moons MS17HA6P4200](https://www.moonsindustries.com/p/nema-17-high-precision-hybrid-stepper-motors/ms17ha6p4200-000004611110015926) or AliExpress [Moons MS17HA6P4200](https://www.aliexpress.com/item/4000378651911.html)

Can be combined with [25 teeth pulleys](https://www.aliexpress.com/item/32994584651.html) (5mm bore / 6mm belt), in which case rotation distance = 50

---

[Cutting jigs for Moroday panel insulation strips](/stl-3mf/Moroday%20cutting%20jigs/)  
Works with Moroday EconoSeal and MultiSeal products (Bunnings)  
Credits @jdndm#3948 on Discord

[Additional wagos mounts](https://github.com/LoganFraser/VoronMods/tree/main/WagoMounts)

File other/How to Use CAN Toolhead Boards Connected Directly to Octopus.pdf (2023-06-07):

How to Use CAN Toolhead Boards Connected Directly to Octopus / Octopus Pro on CanBoot

- Klipper has a new CAN bus feature, the USB to CAN bus bridge communication for Octopus boards (and other compatible MCUs).
- This feature allows the Octopus boards (and other compatible MCUs) to act as a USB to CAN bus adapter. This replaces the need for an adapter like a Raspberry Pi CAN HAT, canable adapter, or the Bigtreetech U2C board.

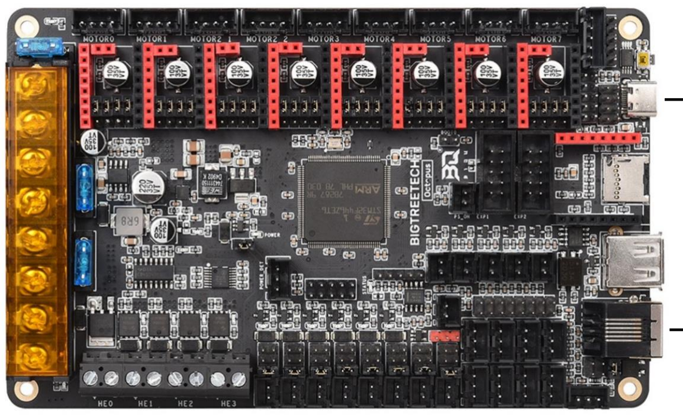
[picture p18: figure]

What is CanBoot?

- CanBoot is a custom bootloader loaded onto your Octopus and EBB board that allows users to update Klipper firmware over USB, UART, or CAN comms without physically having to access the board reset buttons or BOOT jumpers.
- It uses the same ‘make menuconfig’ setup to configure and compile firmware.
- CanBoot is NOT required to use the Klipper USB to CAN bus bridge comms. But I have not tested this comms feature separately.

You Will Need the Following

- USB-A to USB-C cable
- Power supply for Octopus and EBB toolboard (i.e. printer)
- RJ11 or RJ12 telephone cable, crimped to connect EBB board to Octopus
- See wiring info at end of guide. Best to setup wiring before installing software.
- Raspberry Pi, or similar, with Klipper / Moonraker / UI installed and working
- Computer with following software:
- SSH terminal software, I use PuTTY or Windows CMD
- WinSCP, to transfer files between Raspberry Pi and computer
- I also use Windows CMD to do this
- STM32CubeProgrammer
- Download for your computer OS and install
- https://www.st.com/en/development-tools/stm32cubeprog.html#get-software (https://www.st.com/en/development-tools/stm32cubeprog.html%23get-software)

High Level Instructions, for Understanding

1. Install CanBoot on Raspberry Pi, flash firmware to boards
a. Configure and compile CanBoot firmware for Octopus / Pro and EBB
b. Flash CanBoot to boards using STM32CubeProgrammer and computer
2. Setup boards for Klipper
a. Octopus - Setup Klipper for USB to CAN bus bridge, with CAN comms to EBB
b. EBB - Setup Klipper for CAN comms
c. Find serial device for Octopus / Pro on Raspberry Pi
d. Flash Klipper to Octopus / Pro with CanBoot serial command
3. Setup can0 network on Raspberry Pi, power cycle printer
4. Find CAN uuid for Boards
a. Connect EBB to Octopus / Pro, power cycle printer
5. Flash Klipper to EBB board with CanBoot CAN command
6. Printer Config Update and General Tips
7. How to Use CanBoot to update boards, Tips

Okay, enough talking! Let’s get started!

Instructions________________________________________________________________________

1. Install CanBoot on Raspberry Pi, flash firmware to boards

Start your SSH terminal.

sudo apt-get install git -y #Do this if you haven’t installed git yet…

git clone https://github.com/Arksine/CanBoot

cd CanBoot

make menuconfig

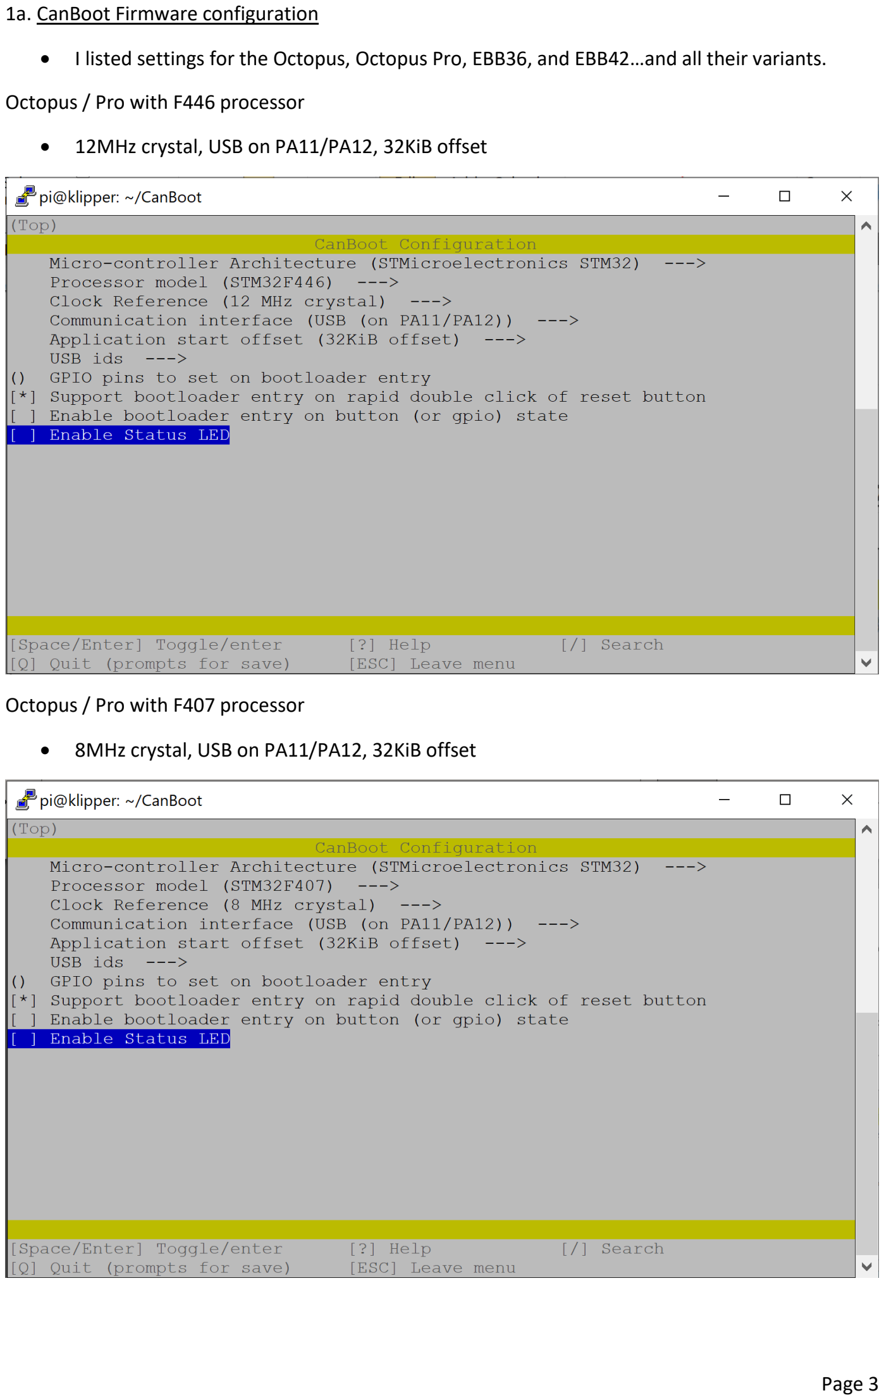
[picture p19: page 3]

1a. CanBoot Firmware configuration

- I listed settings for the Octopus, Octopus Pro, EBB36, and EBB42…and all their variants.

Octopus / Pro with F446 processor

- 12MHz crystal, USB on PA11/PA12, 32KiB offset

Octopus / Pro with F407 processor

- 8MHz crystal, USB on PA11/PA12, 32KiB offset

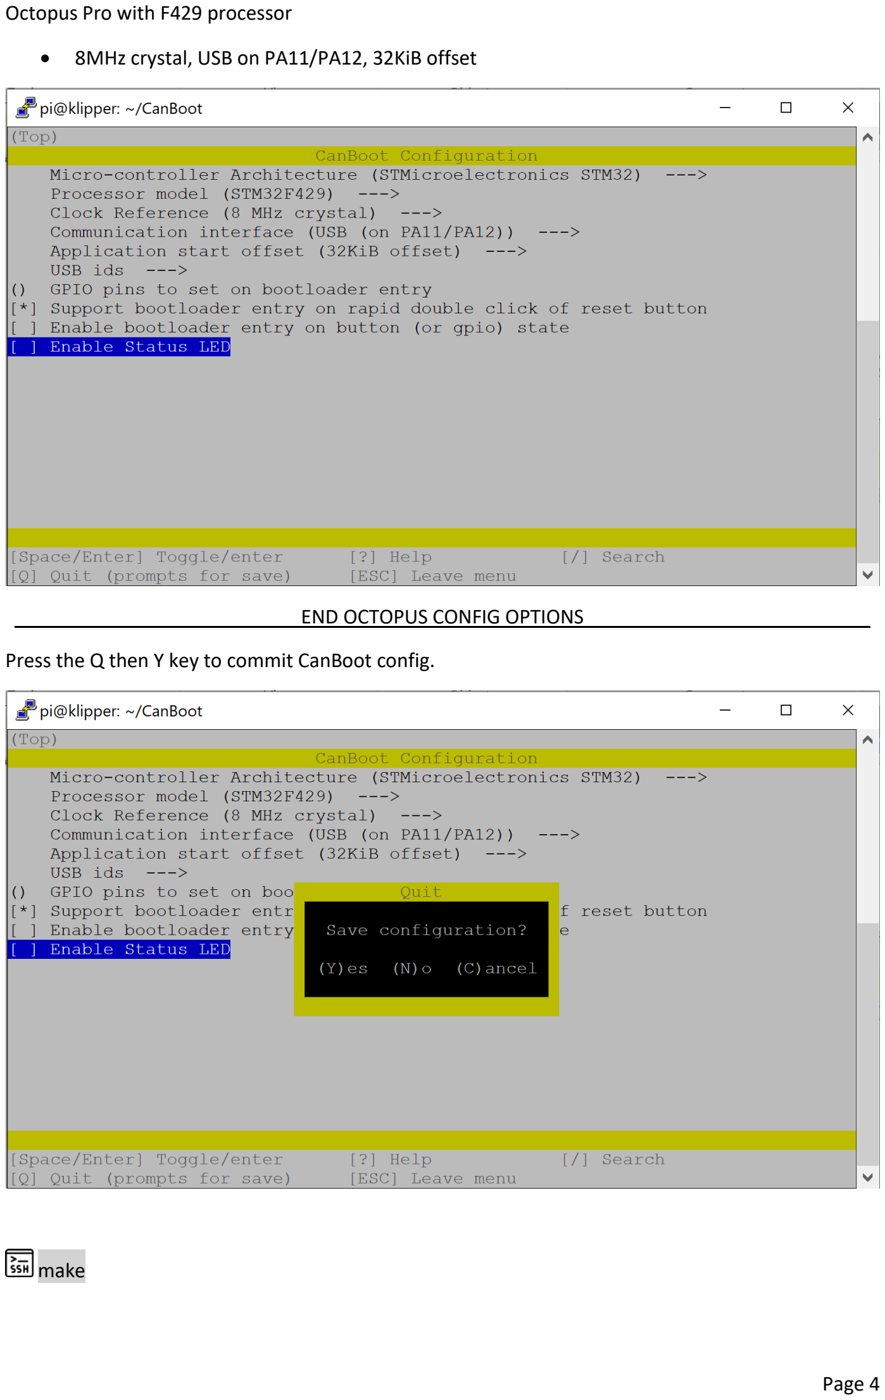
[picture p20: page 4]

Octopus Pro with F429 processor

- 8MHz crystal, USB on PA11/PA12, 32KiB offset

___________________________END OCTOPUS CONFIG OPTIONS___________________________

Press the Q then Y key to commit CanBoot config.

make

You have now created a canboot.bin firmware file for your Octopus board. My approach is to now make the CanBoot firmware for the EBB board. But if you do this now it will override the Octopus firmware you just created. So do the following:

On your computer, open a Windows CMD terminal

Type: pscp -C pi@<IP_ADDRESS>:/home/pi/CanBoot/out/canboot.bin octopus_canboot.bin

- Make sure to replace <IP_ADDRESS> with your Pi IP address or network name, like fluiddpi.local

NOTE: You can also manually move the canboot.bin file to your computer with WinSCP. Make sure to name it octopus_canboot.bin (or similar). We will be moving an ebb_canboot.bin file next.

…Back to the Raspberry Pi SSH terminal

make clean

make menuconfig

EBB36 / EBB42 v1.0 with F072 processor

- 8MHz crystal, CAN bus on PB8/PB9, 8KiB offset, 500000 CAN bus speed

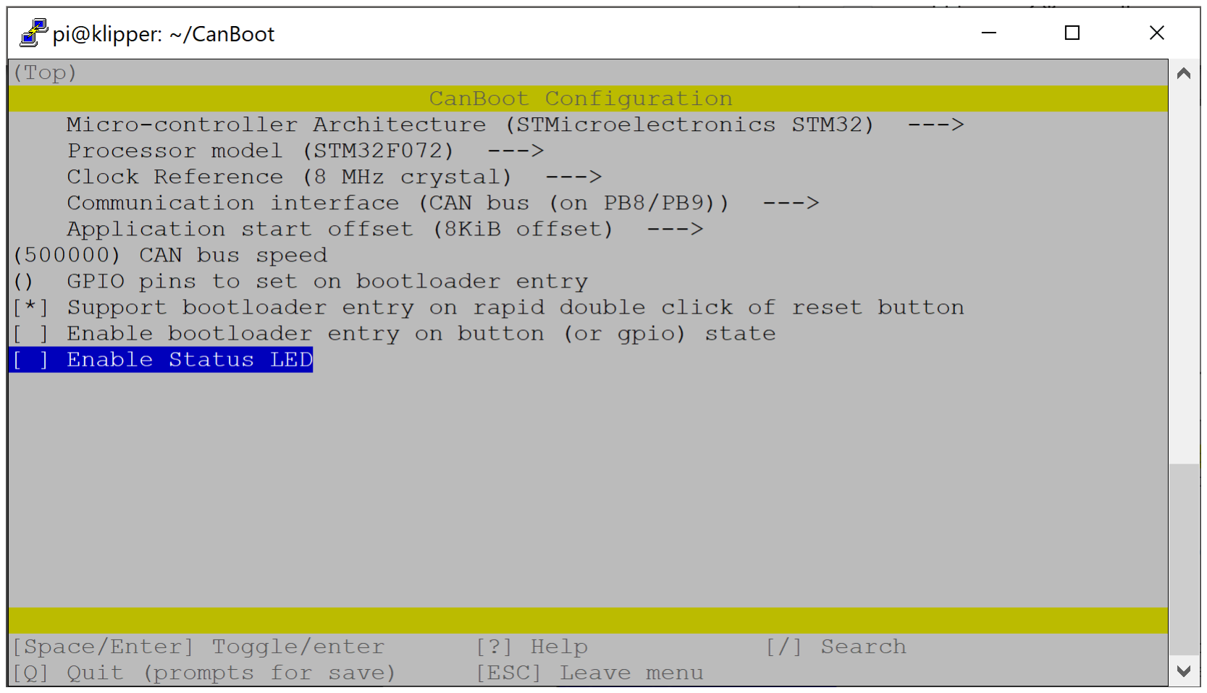
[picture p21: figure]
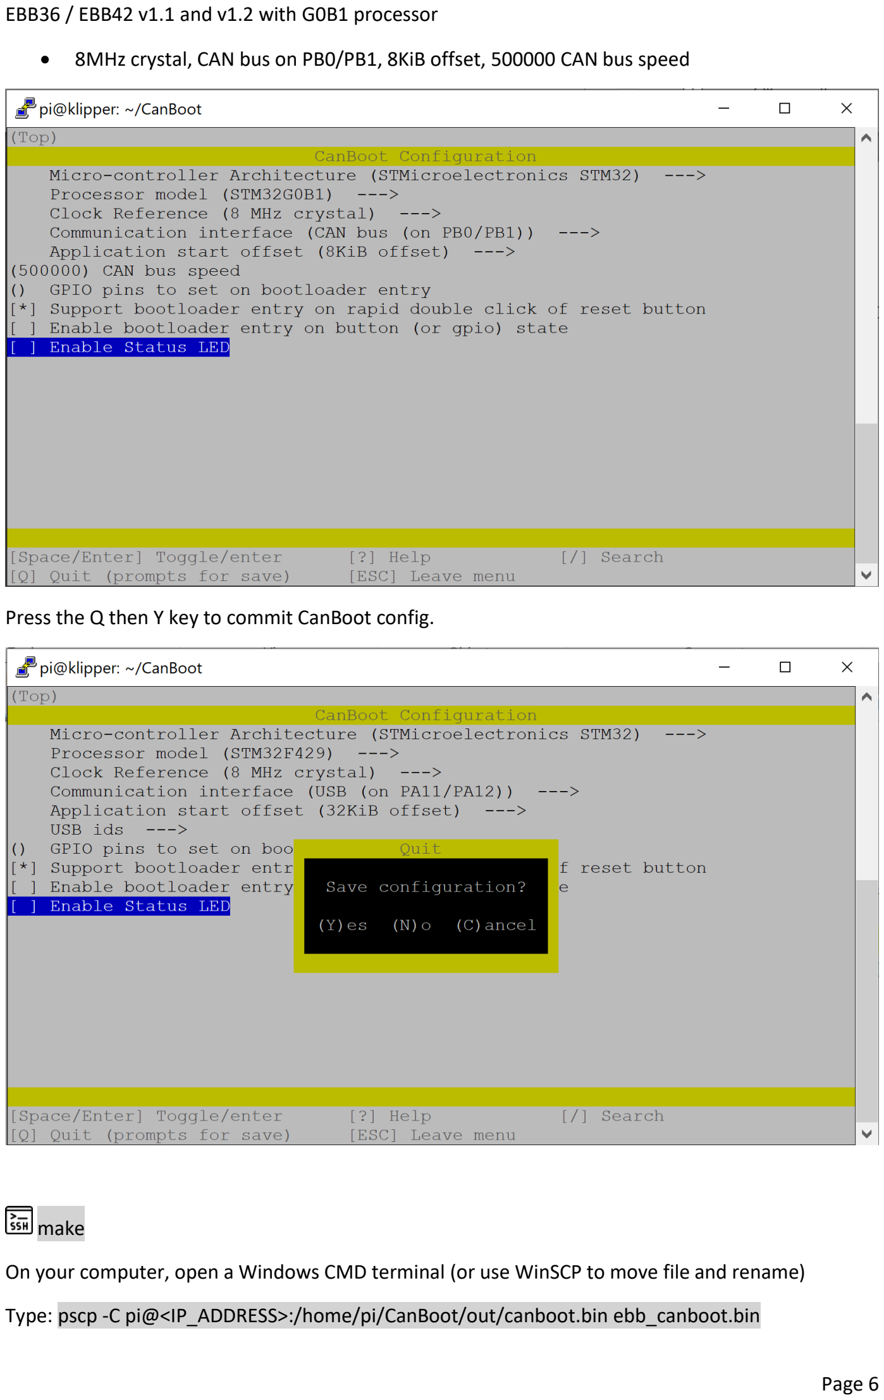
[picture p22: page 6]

EBB36 / EBB42 v1.1 and v1.2 with G0B1 processor

- 8MHz crystal, CAN bus on PB0/PB1, 8KiB offset, 500000 CAN bus speed

Press the Q then Y key to commit CanBoot config.

make

On your computer, open a Windows CMD terminal (or use WinSCP to move file and rename)

Type: pscp -C pi@<IP_ADDRESS>:/home/pi/CanBoot/out/canboot.bin ebb_canboot.bin

- Make sure to replace <IP_ADDRESS> with your Pi IP address or network name, like fluiddpi.local

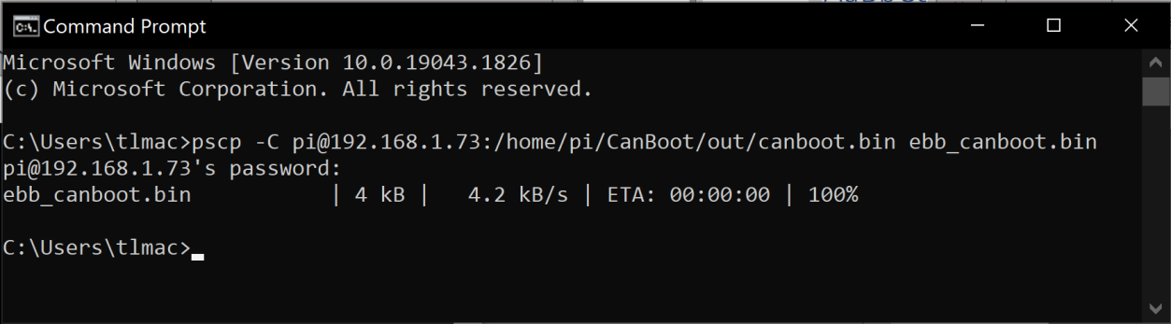
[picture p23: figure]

Your two CanBoot firmware files are now on your computer (in your user folder). Next step is to flash CanBoot to your boards.

1b. Flash CanBoot using STM32CubeProgrammer

You’ll need to put your boards into DFU mode and connect to the computer using a USB-A to USB-C cable. Boot instructions for the Octopus and Octopus Pro are below:

Make sure the power is off to the Octopus board

- To start have the USB-C to USB-A cable connected between the Windows PC and the Octopus Board.
- Remove the USB-C power jumper and place a jumper on the Boot0 header.

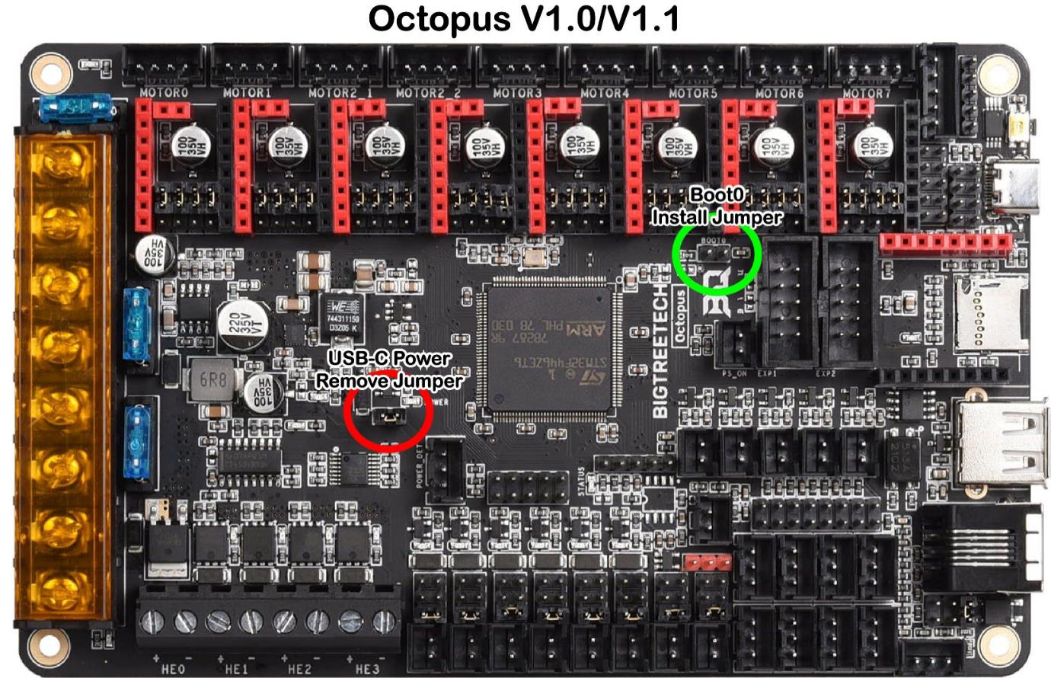
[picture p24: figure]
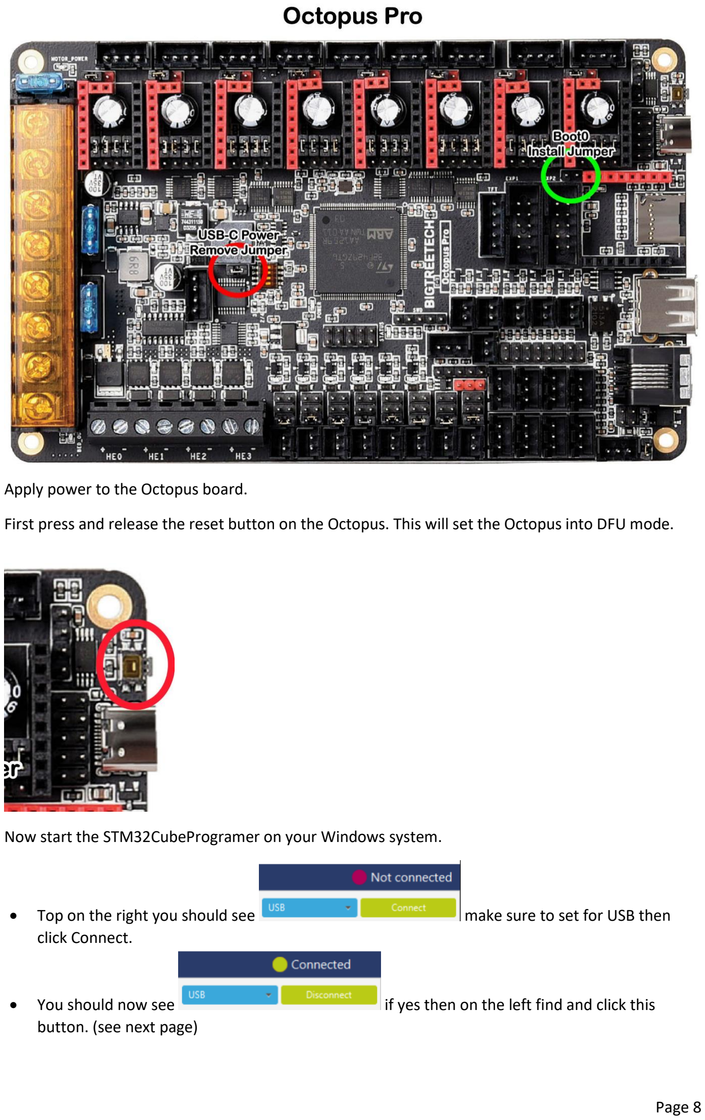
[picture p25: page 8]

Apply power to the Octopus board.

First press and release the reset button on the Octopus. This will set the Octopus into DFU mode.

Now start the STM32CubeProgramer on your Windows system.

- | Top on the right you should see | make sure to set for USB then
| click Connect.
- | You should now see | if yes then on the left find and click this
| button. (see next page)

- For CanBoot and Klipper to work correctly we need to wipe the flash memory by clicking this button.

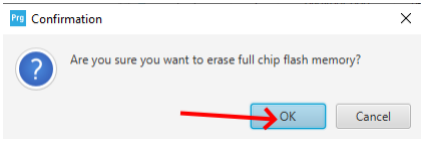
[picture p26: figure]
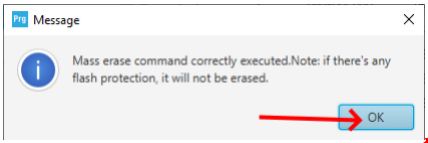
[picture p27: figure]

- Go back to main page by clicking on this button

- Select (1) “Open File” tab, find the octopus_canboot.bin file, and (2) download to your Octopus board. (3) Click Disconnect when done.

Power off your Octopus board. Remove the jumper from BOOT0.

Now you’ll flash your EBB toolboard.

This step will power the toolboard from USB only. Place a jumper on VBUS header.

EBB36 / EBB42 v1.0

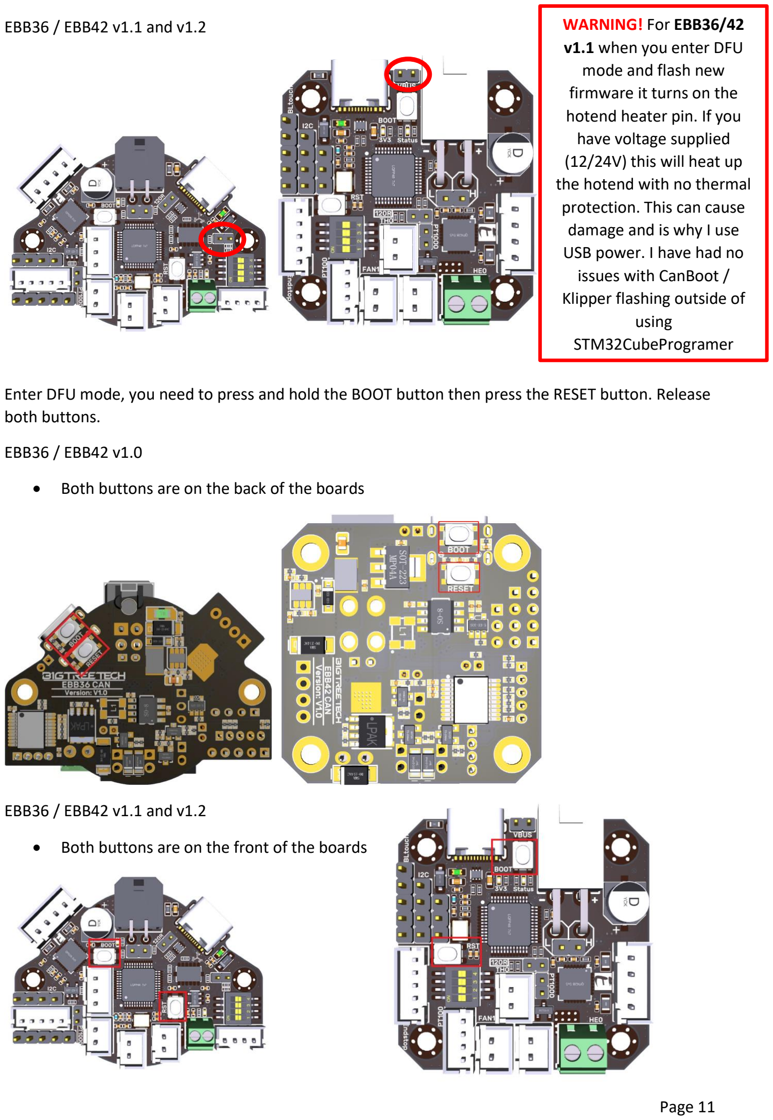
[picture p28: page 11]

EBB36 / EBB42 v1.1 and v1.2

Enter DFU mode, you need to press and hold the BOOT button then press the RESET button. Release both buttons.

EBB36 / EBB42 v1.0

- Both buttons are on the back of the boards

EBB36 / EBB42 v1.1 and v1.2

- Both buttons are on the front of the boards

WARNING! For EBB36/42
v1.1 when you enter DFU
mode and flash new
firmware it turns on the
hotend heater pin. If you
have voltage supplied
(12/24V) this will heat up the hotend with no thermal protection. This can cause damage and is why I use
USB power. I have had no
issues with CanBoot /
Klipper flashing outside of using
STM32CubeProgramer

Now start the STM32CubeProgramer on your Windows system.

- | Top on the right you should see | make sure to set for USB then
| click Connect.
- | You should now see | if yes then on the left find and click this
| button.
- For CanBoot and Klipper to work correctly we need to wipe the flash memory by clicking this button.

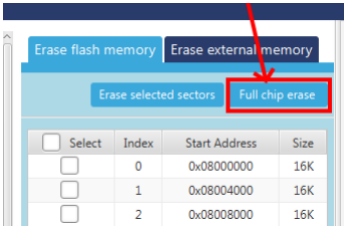
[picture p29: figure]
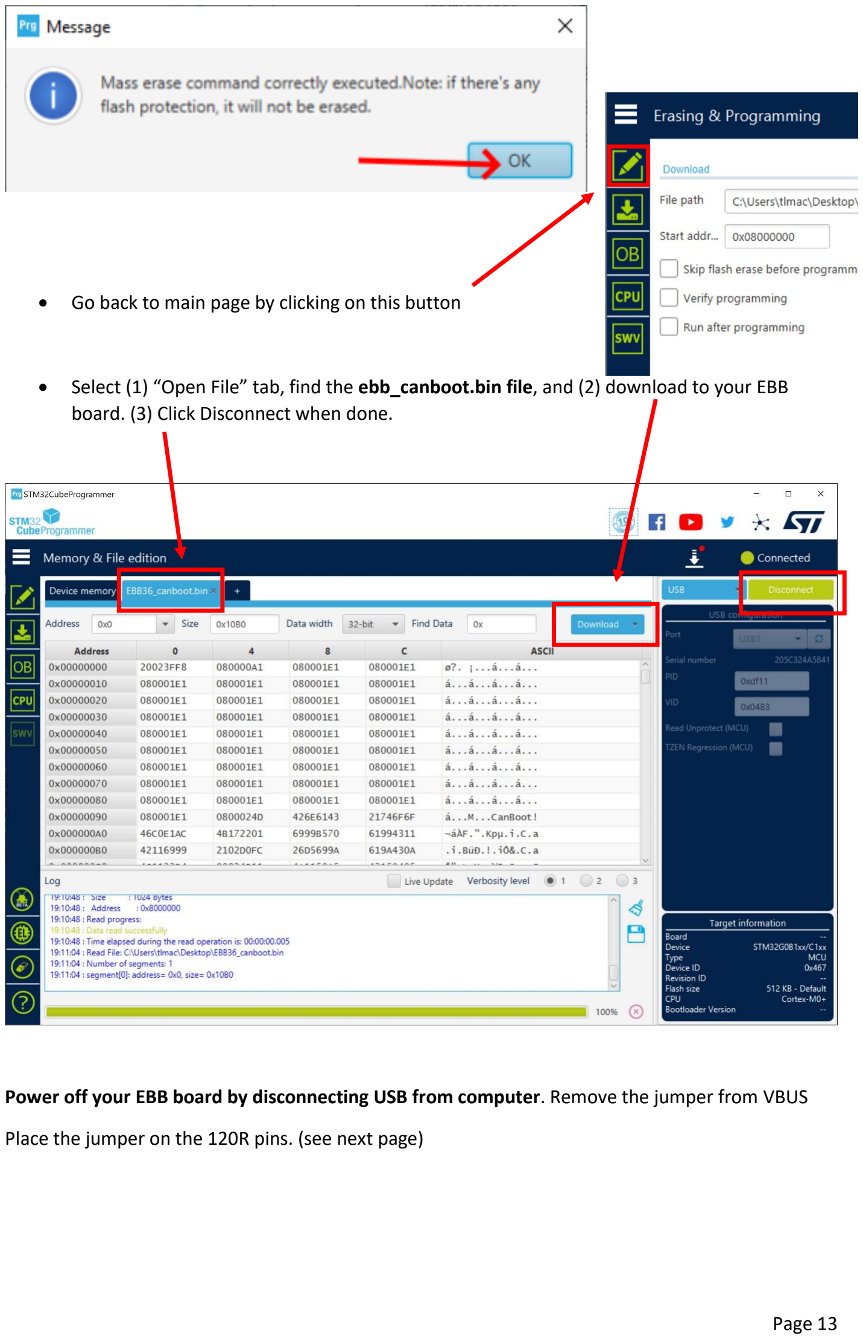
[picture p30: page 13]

- Go back to main page by clicking on this button
- Select (1) “Open File” tab, find the ebb_canboot.bin file, and (2) download to your EBB board. (3) Click Disconnect when done.

Power off your EBB board by disconnecting USB from computer. Remove the jumper from VBUS

Place the jumper on the 120R pins. (see next page)

EBB36 / EBB42 v1.0

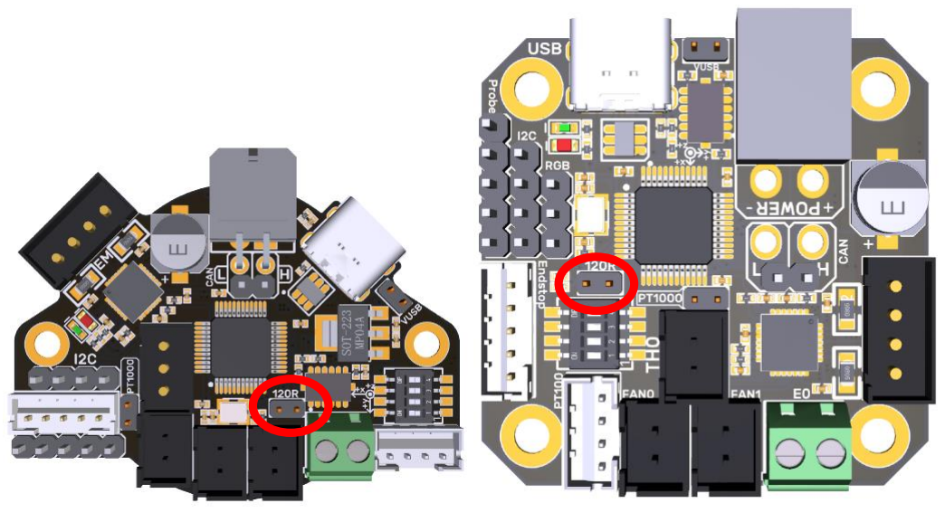
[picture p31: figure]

EBB36 / EBB42 v1.1 and v1.2

Set aside the EBB toolboard for now.

2. Setup Octopus / Pro for Klipper

Go back to your SSH terminal window.

cd ~/klipper

make menuconfig

2a. Octopus - Setup Klipper for USB to CAN bus bridge, with CAN comms to EBB

You will now setup the new USB to CAN bus bridge on your Octopus / Pro board. Below are the Klipper config options for each board. Make sure to have “Enable extra low-level configuration options” selected.

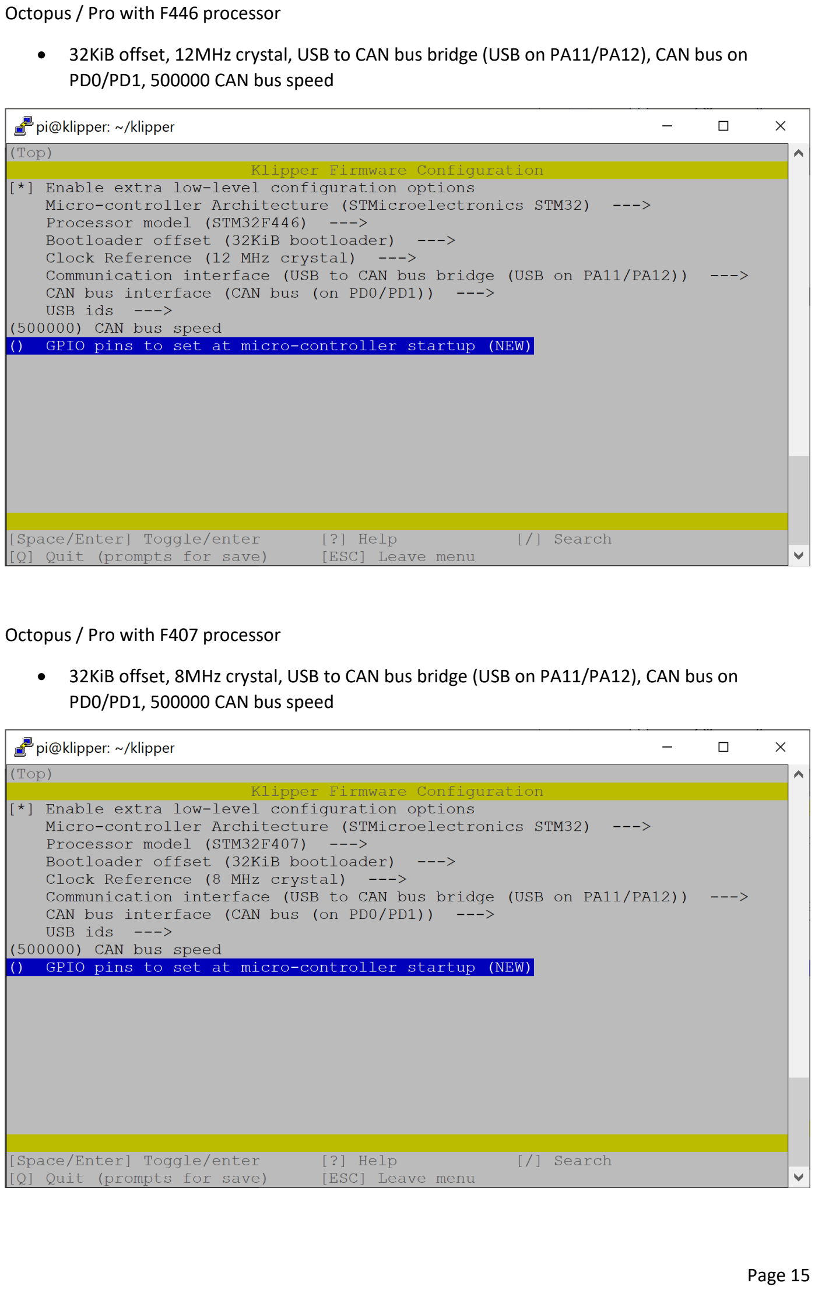
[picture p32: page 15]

Octopus / Pro with F446 processor

- 32KiB offset, 12MHz crystal, USB to CAN bus bridge (USB on PA11/PA12), CAN bus on PD0/PD1, 500000 CAN bus speed

Octopus / Pro with F407 processor

- 32KiB offset, 8MHz crystal, USB to CAN bus bridge (USB on PA11/PA12), CAN bus on PD0/PD1, 500000 CAN bus speed

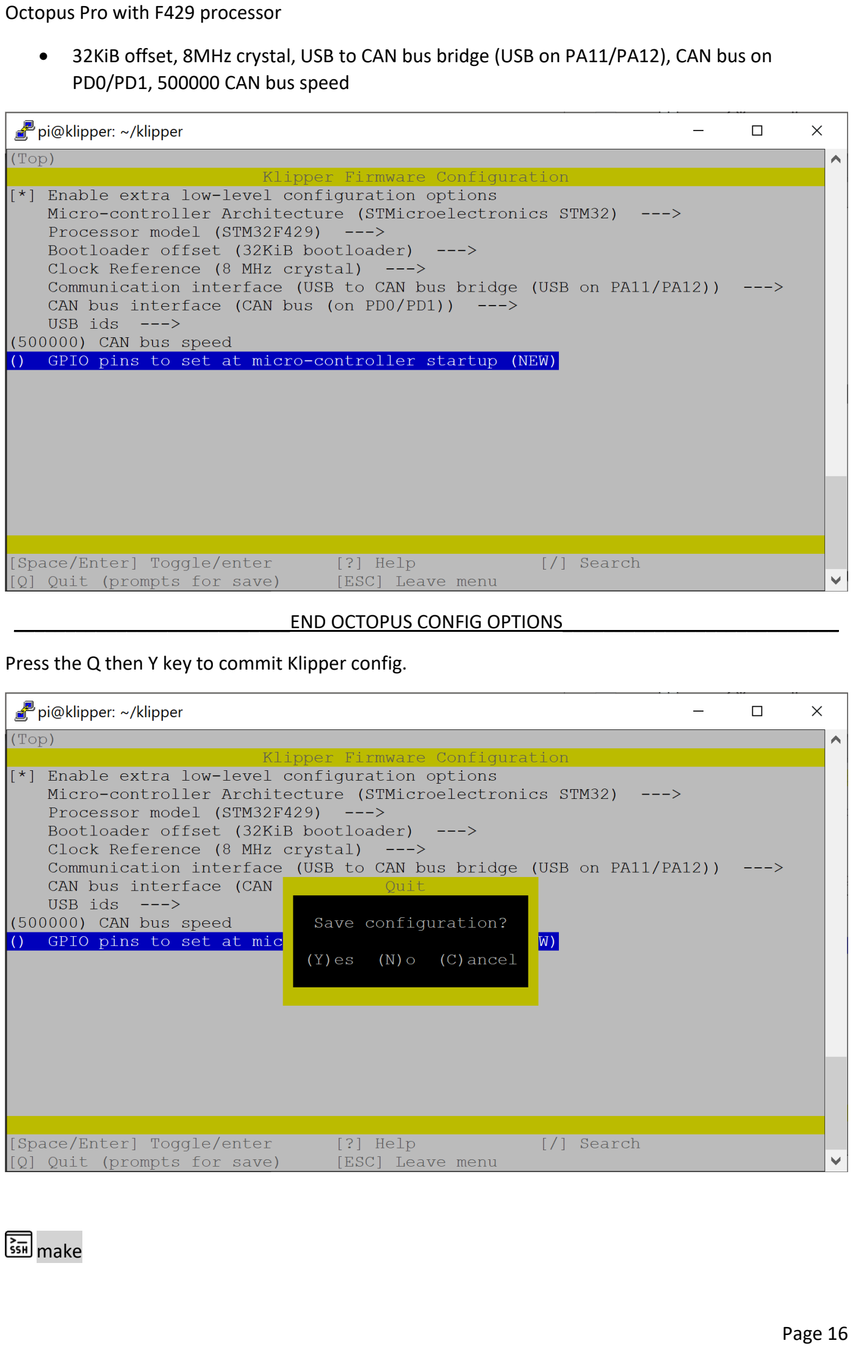
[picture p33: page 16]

Octopus Pro with F429 processor

- 32KiB offset, 8MHz crystal, USB to CAN bus bridge (USB on PA11/PA12), CAN bus on PD0/PD1, 500000 CAN bus speed

___________________________END OCTOPUS CONFIG OPTIONS___________________________

Press the Q then Y key to commit Klipper config.

make

NOTE:

Just like with the CanBoot firmware we will be making Klipper firmware for the Octopus / Pro board and the EBB board. Since we are already compiling Klipper firmware, I like to compile the EBB Klipper firmware now. But if we do, then the Octopus Klipper firmware we just made will be overwritten. So:

mv ~/klipper/out/klipper.bin octopus_klipper.bin

make clean

NOTE:

This moves the klipper firmware file to the klipper folder and renames it octopus_klipper.bin then deletes the compile files and folders, including /klipper/out

2b. EBB - Setup Klipper for CAN comms

make menuconfig

EBB36 / EBB42 v1.0 with F072 processor

- 8KiB bootloader, 8MHz crystal, CAN bus on PB8/PB9, 500000 CAN bus speed

EBB36 / EBB42 v1.1 / v1.2 with G0B1 processor

- 8KiB bootloader, 8MHz crystal, CAN bus on PB0/PB1, 500000 CAN bus speed

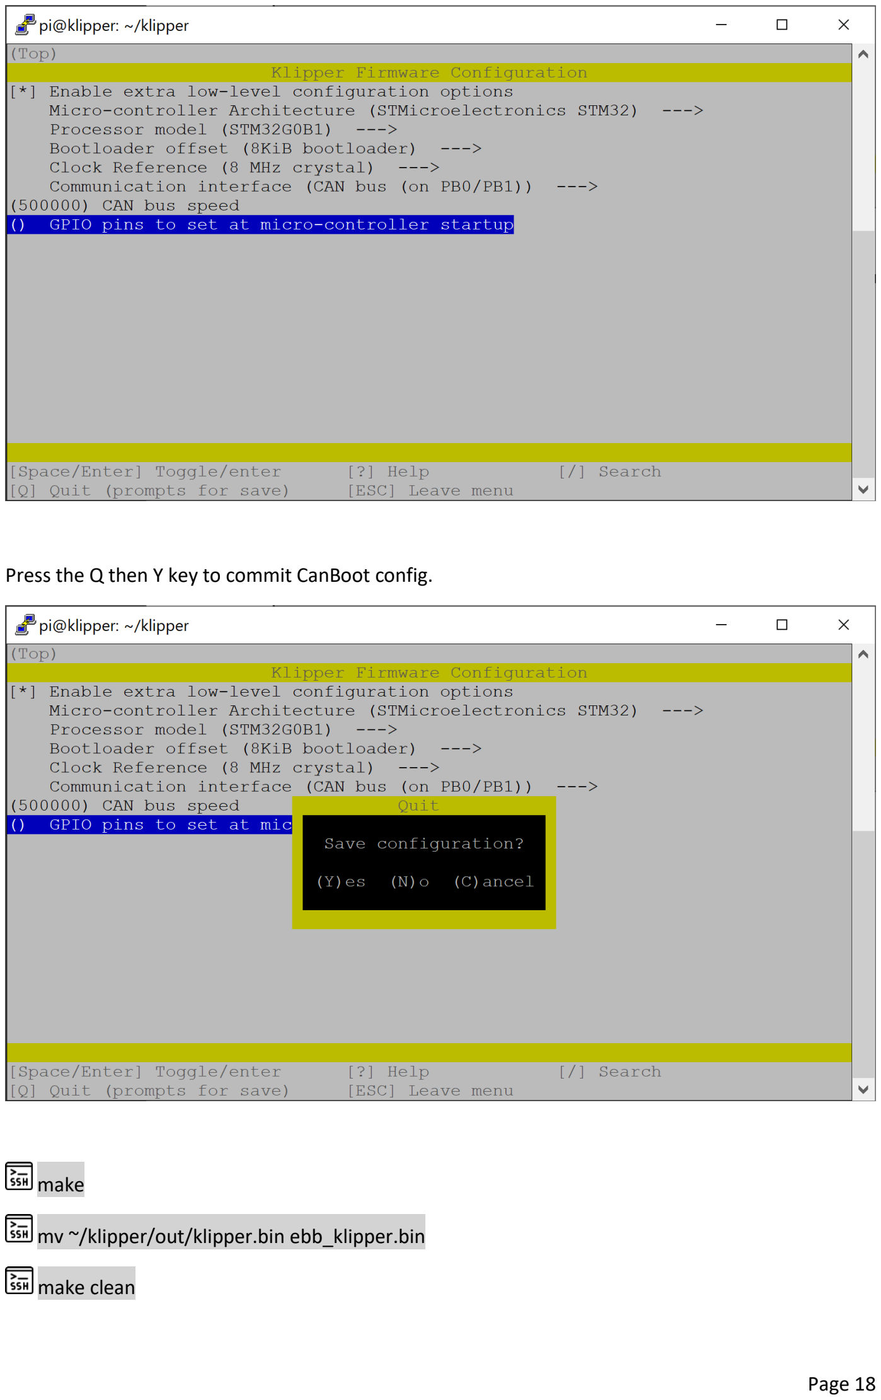
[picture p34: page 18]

Press the Q then Y key to commit CanBoot config.

make

mv ~/klipper/out/klipper.bin ebb_klipper.bin

make clean

2c. Find serial device for Octopus / Pro on Raspberry Pi

Connect your Octopus / Pro board to the Raspberry Pi with a USB-A to USB-C cable…connected to the USB-C port on the Octopus board. Power on your printer.

cd

ls /dev/serial/by-id/*

This will give you something similar to below. YOUR DEVICE WILL BE DIFFERENT!

Copy this, for example:

/dev/serial/by-id/usb-CanBoot_stm32f429xx_350026000B50314B33323220-if00

2d. Flash Klipper to Octopus / Pro with CanBoot serial command

cd CanBoot/scripts

pip3 install pyserial

…this only has to be done once

python3 flash_can.py -f ~/klipper/octopus_klipper.bin -d <serial_device>

NOTE: Replace <serial_device> with the path you copied earlier…

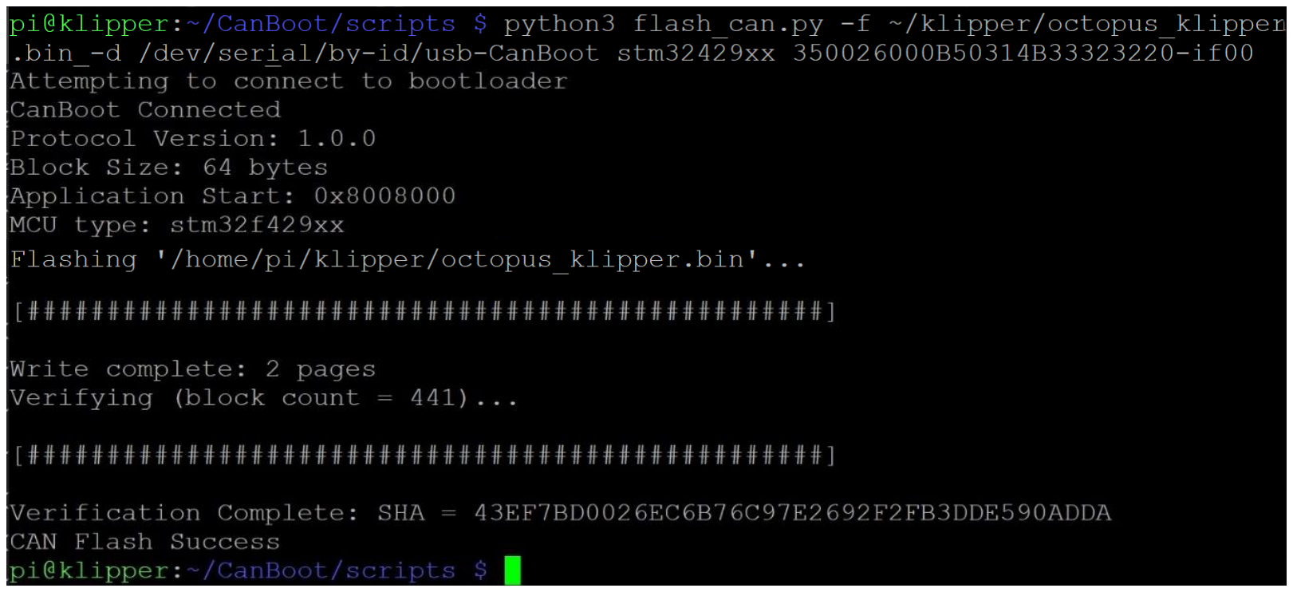
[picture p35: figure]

NOTE: The Octopus board communicates over USB initially. Only this flash (and Klipper updates, more on that later) use the serial device path. The Octopus board now has a CAN uuid…let’s find it!

3. Setup can0 Network on Raspberry Pi, Power Cycle Printer

Now we need to enable the can0 network and set it up so that we can have CAN bus working

cd

sudo nano /etc/network/interfaces.d/can0

- Copy and paste the following:

allow-hotplug can0
iface can0 can static
bitrate 500000
up ifconfig $IFACE txqueuelen 128

Ctrl – X to EXIT.

Key Y for YES, and ENTER.

Power off your printer. Time to plug in your EBB toolboard. Plug power and can data cables into EBB. Plug RJ11 or RJ12 connector into Octopus / Pro board.

Power on your printer.

NOTE:

We just created the can0 interface as a hot-plug network. This means that when something changes to devices, or new devices are connected, the network reacts. Power cycling the printer is a change that the can0 network detects and configures the Octopus to work as a CAN device. Also, this hot-plug option seems to make “firmware_restarts” smoother.

4. Find CAN uuid for Octopus / Pro

Now that can0 is setup, let’s make sure it is up and running.

ifconfig

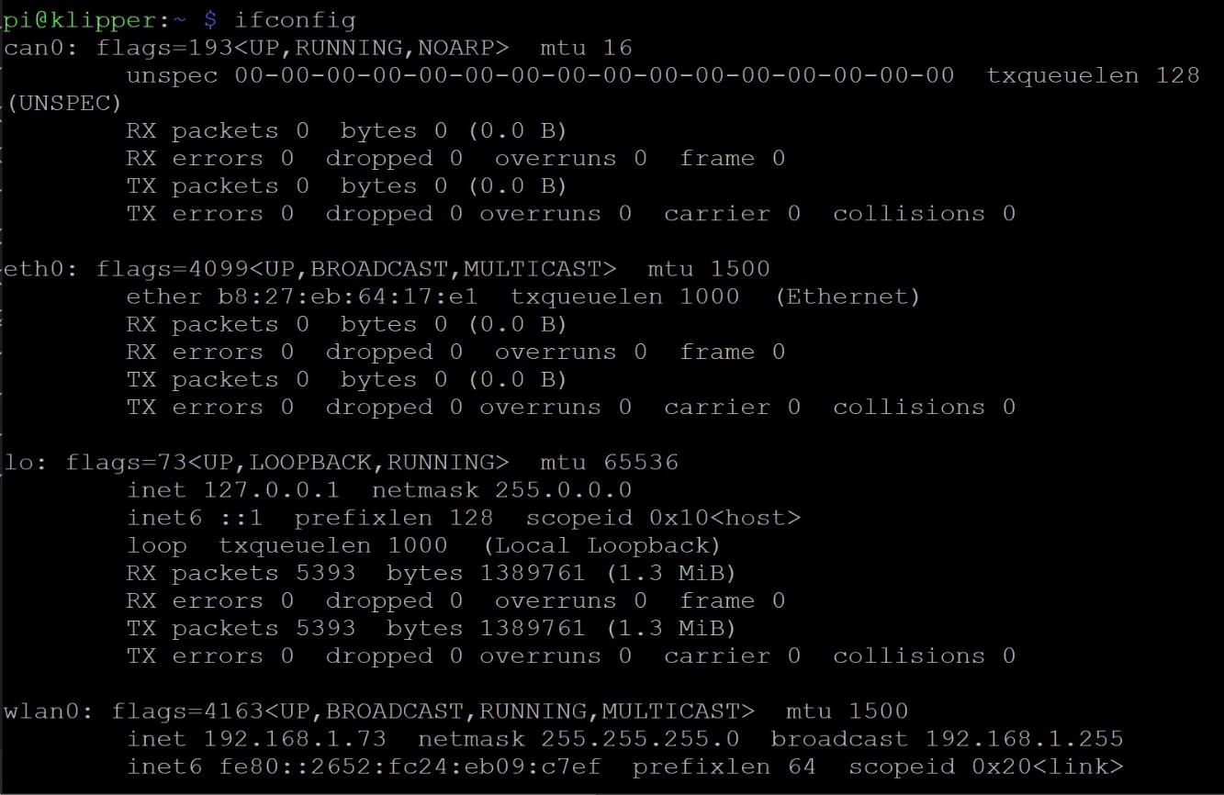
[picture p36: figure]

You should get results similar to this. We are looking for the can0 on top. Success!

NOTE: If this doesn’t work try to turn off power to your printer and reboot your Raspberry Pi. Wont booted back up, open a SSH terminal and try ifconfig again. Can0 won’t show up. Power on your printer and then try ifconfig. Should have can0 up and running.

cd CanBoot/scripts

python3 flash_can.py -i can0 -q

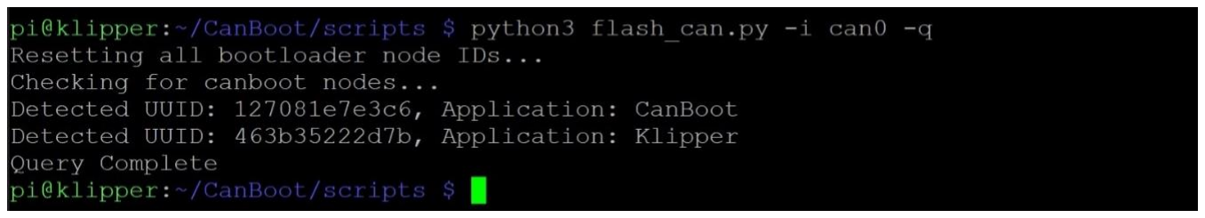
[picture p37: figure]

In this instance both EBB and Octopus are detected. The EBB only has CanBoot on it while the Octopus has Klipper. It is obvious which is which. Save both for later.

5. Flash Klipper to EBB board with CanBoot CAN command

python3 flash_can.py -f ~/klipper/ebb_klipper.bin -u <ebb_uuid>

NOTE: Replace <ebb_uuid> with the CAN uuid found before. The EBB is labelled with “CanBoot”. In this case mine is 127081e7e3c6

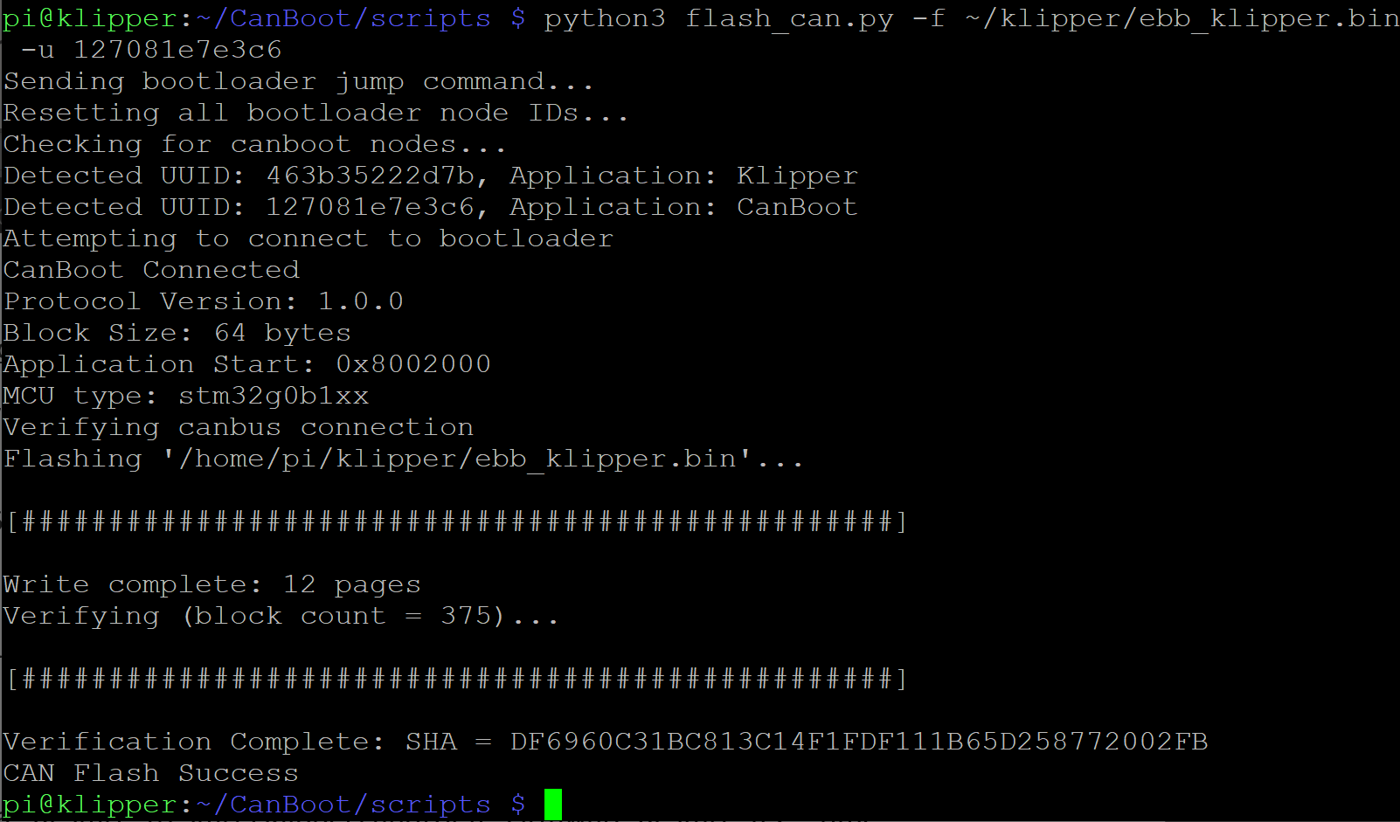
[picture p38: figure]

cd ~/klipper

rm octopus_klipper.bin ebb_klipper.bin

6. Printer Config Update and General Tips

Edit your printer.cfg to now include your new CAN uuid. For example:

[mcu]
canbus_uuid: 463b35222d7b

[mcu EBBCan]
canbus_uuid: 127081e7e3c6

Save and restart.

If you have issues here, try a “Restart” (restarts Klipper) and/or a “Firmware Restart” a 2nd time.

- The issue is can0 network disconnects when the restart causes a power cycle on your printer. The timing can be too fast and the can0 network doesn’t properly come back up. Another restart command is sometimes needed.
- | According to Klipper CANBUS docs, you might need to issue | sudo ip up in a SSH terminal to
restart the can0 network. I haven’t had to do this. But this might be useful during initial setup.

- | You can also use | sudo ip link set up can0 type can bitrate 500000 in a SSH terminal to start
can0 if it isn’t coming up with ifconfig. I have used this, but find that if the install instructions are followed then I don’t need it.
- See Klipper docs on CANBUS for official information https://www.klipper3d.org/CANBUS.html#usb-to-can-bus-bridge-mode
7. How to Use CanBoot to update boards, Tips

With CanBoot and Klipper now properly flashed to your Octopus / Pro board and EBB toolboard you now have two devices with unique CAN uuid on can0 network. But how to use CanBoot to upgrade Klipper firmware!?

When you run python3 flash_can.py | the python script should trigger the board to go into DFU
mode, to access CanBoot on the board and flash the Klipper update. I can’t cleanly get this to work with my Octopus Pro with F429 processor.
- Flashing with CAN uuid gives an error. Trying to use the original serial ID also gives an error.
- How I get it to work:
- Make Klipper firmware for Octopus board, cd to CanBoot/scripts
- I run: python3 flash_can.py -f ~/klipper/octopus_klipper.bin -u 463b35222d7b
- Note I am still moving and renaming firmware files. If you don’t want to do this then leave out: -f ~/klipper/octopus_klipper.bin and CanBoot defaults to using default location of Klipper firmware [ ~/klipper/out/klipper.bin ]
- CanBoot throws an error. If I try ifconfig, the can0 network is down
- Now if I try ls /dev/serial/by-id/* I get a serial ID:
- /dev/serial/by-id/usb-CanBoot_stm32f429xx_350026000B50314B33323220-if00
- Same as earlier…
- Now I run:
- python3 flash_can.py -f ~/klipper/octopus_klipper.bin -d /dev/serial/by-id/usb-CanBoot_stm32f429xx_350026000B50314B33323220-if00
- And CanBoot works and flashes Klipper update!
- I can now update the EBB with: python3 flash_can.py -f ~/klipper/ebb_klipper.bin -u 127081e7e3c6

Long story short;

1. Try to flash Octopus board with CAN uuid, it will fail and can0 network is down.
2. Now you can flash Octopus board with serial ID.
3. Lastly you can flash EBB board with CAN uuid.

CAN Bus Wiring on next page…

RJ11 / RJ12 CAN bus Wiring Info

To connect your EBB36/42 or other CAN enabled toolboard directly to the Octopus boards you need to use the RJ11 / RJ12 telephone port.

The easiest option is to use a 2-3 meter telephone cable and cut off one end. Crimp for Molex MiniFit or Molex MicroFit connector, depending on your CAN toolboard. The RJ11/12 connector goes to the Octopus board.

- This does not allow for twisted wire, which is recommended for CAN bus wiring.
- I have the 4 wire RJ11 telephone cable running directly to my EBB36, no twisted wire. No issues on my end but I will work to get twisted wire setup in the future.

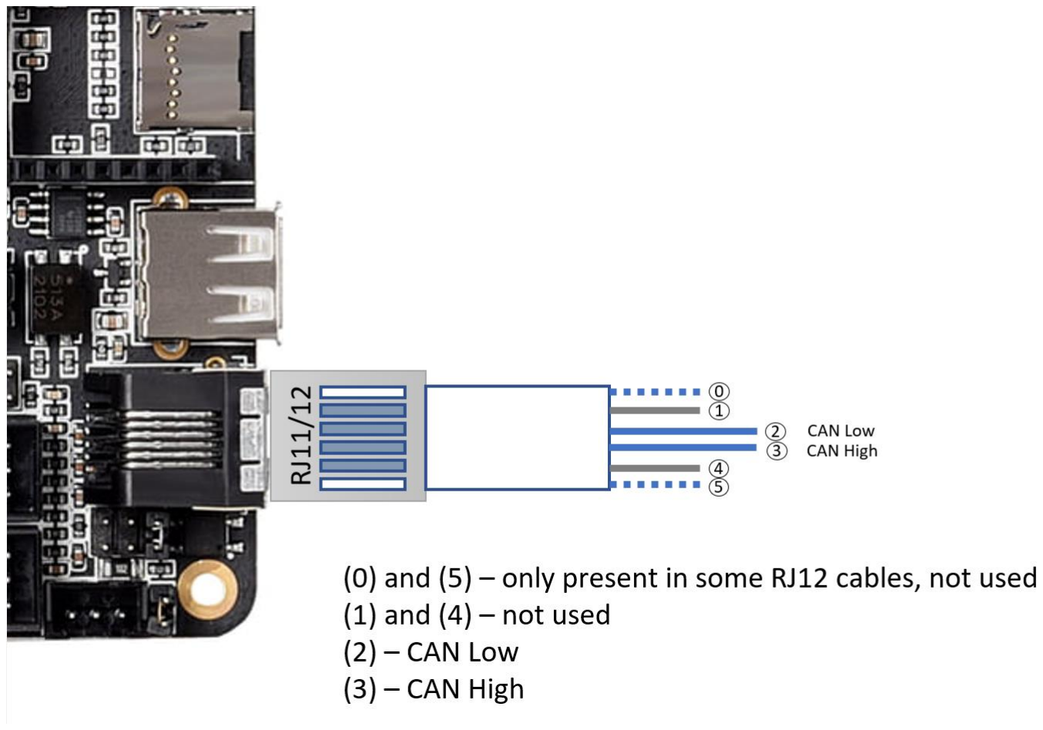
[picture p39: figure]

When you plug in the RJ11/12 cable to the Octopus board, the wiring (from top down) is as above. DO NOT RELY ON WIRE COLOURS. For example:

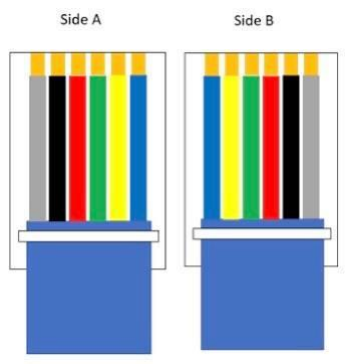
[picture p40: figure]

If plugging in a RJ12 cable with SIDE A your CAN Low wire is GREEN and CAN High wire is RED.

If plugging in a RJ12 cable with SIDE B your CAN Low wire is RED and CAN High wire is GREEN.

The colour of your wiring setup will be situational.

Take note of the wiring that you have plugged into the Octopus board. Wire 2 is your CAN Low connection. Note the colour of the wire and make sure it goes to CAN_L on the EBB end. Same thing for the CAN High on Wire 3. That colour wire goes to CAN_H on the EBB end.

You must also supply 12V or 24V directly to the EBB toolboard. Run 18awg directly from your power supply. Example EBB connections are below. Again, colours on the diagrams do not indicate wire colours.

EBB36

EBB42

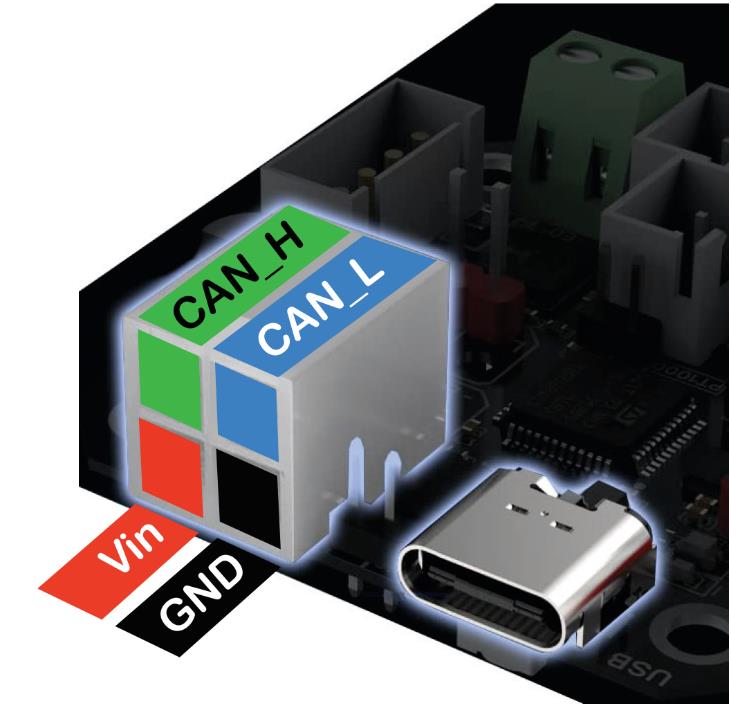
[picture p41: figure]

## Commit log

2023-03-20 files to print added
    [Foldable_Spool_Holder.3mf, SSD SideMount.3mf, SSD to Pi with Fan.3mf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]
2023-03-31 List & Files update
    [Trident_Y_Overkill_Support.stl, Trident_Y_Support.stl]
2023-04-09 ReadMe update & Files addition
    [BTT Smart Filament Sensor Frame Mount.stl, LDO_exhaust_cover.3mf, exhaust_cover with quick connect.stl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]
2023-04-21 Update & octopus color pin doc
2023-05-16 Create Pi Buster KlipperScreen Instructions
2023-08-14 Upload macros magprobe
    [autoz.cfg, klicky-bed-mesh-calibrate.cfg, klicky-macros.cfg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]
